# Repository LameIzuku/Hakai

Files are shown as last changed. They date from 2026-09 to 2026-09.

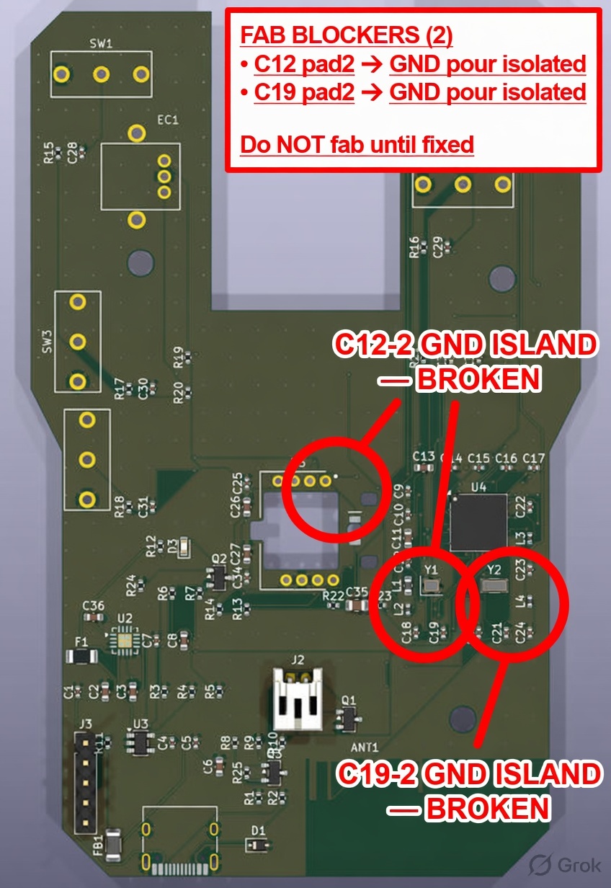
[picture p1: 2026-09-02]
hardware/v6-final-v2/FAB_BLOCKERS_GND_C12_C19_marked.jpg

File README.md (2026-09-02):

# Hakai

Hardware, firmware-adjacent tooling and web assets for the Hakai mouse.

## Repository layout

```
hardware/            KiCad projects, one folder per design revision
  rev2/                Jul 2026  - hakai_mouse_rev2
  v5/                  Jul 2026  - hakai_mouse_v5
  final/               Jul 2026  - hakai_mouse_final
  v6/                  Jul 2026  - hakai_mouse_v6
  v6-final-v2/         Aug 2026  - hakai_mouse_v6   <-- CURRENT / authoritative
site/                Product site (static HTML + assets)
docs/                Design notes and schematic write-ups
tools/               Helper scripts (Blender MCP addon, etc.)
archive/             Local-only zip snapshots (not tracked - see .gitignore)
```

Revision order is chronological by board file date. **`hardware/v6-final-v2/` is
the authoritative design**; the other folders are kept for history and should not
be fabricated from.

## Current board: `hardware/v6-final-v2`

| | |
|---|---|
| Board | 70.10 x 110.10 mm, 2 layer, 0.8 mm |
| Copper | 1 oz (35 um) both outer layers |
| Min track / clearance | 0.10 mm / 0.072 mm (QFN courtyards only; 0.20 mm elsewhere) |
| Min drill | 0.20 mm |
| Mounting holes | 3x NPTH 3.2 mm at (114,72), (155,130), (160,74) |

### Assembly note - MH3

MH3 is the NPTH 3.2 mm hole at **(155.000, 130.000)**. The ground pour is held
back 1.40 mm from the hole edge by a dedicated keepout. **Fit a nylon or other
insulating washer / standoff at MH3** - do not use a bare metal washer.

### Fabrication status: READY

The saved zone fill is current. Verified with KiCad 10.0.5:

- DRC **without** `--refill-zones` (i.e. against the *stored* fill that gerber
  export actually plots): **0 violations, 0 unconnected**
- Ground pour clearance to the MH3 hole edge: **1.3964 mm (F.Cu) / 1.3974 mm
  (B.Cu)**, measured in the exported gerber
- Mounting-hole drill: 3x NPTH 3.2 mm, MH3 at `X155.0 Y-130.0`

Ready-to-send package: **`gerbers/fab_ready/`** - 9 gerbers, merged Excellon
drill (PTH + NPTH, MixedPlating), `.gbrjob`, and `FAB_NOTES.txt`.

> **Always re-fill zones before exporting gerbers.** Gerber export plots the
> *saved* fill, not a live one. If you edit routing, run `Edit > Fill All Zones`
> (B), confirm DRC is 0/0 with "Refill all zones" *unchecked*, then save and
> re-export. An earlier revision of this board shipped a stale fill in which the
> GND pour overlapped SWDIO and VBAT_SENSE at 0.0000 mm clearance.

### Known deviation - VBAT_SENSE under the RF feed

`VBAT_SENSE` on B.Cu crosses beneath `RF_FEED` on F.Cu, with the nearest plane
cut **~1.79 mm from the antenna feed pad ANT1.1** at (138.000, 140.000).
Crossing counts are unchanged from the pre-reroute baseline (2x RF_FEED, 2x ANT,
1x RF1, all broadside through the 0.8 mm dielectric), but the baseline's closest
cut was 8.83 mm out. Accepted for prototype. If return loss disappoints, look
here before touching the match component values.

## Excluded from version control

| Excluded | Size | Why |
|---|---|---|
| `archive/*.zip` | 163 MB + 64 MB | Self-archives of this tree; the 163 MB file exceeds GitHub's 100 MB hard limit |
| `**/tools/fr/*.jar` | 58 MB each | Freerouting - download from [freerouting/freerouting](https://github.com/freerouting/freerouting/releases) |
| `.history/` | - | VS Code Local History; contains nested git repos |
| `*.kicad_prl` | - | Per-user KiCad local settings |

`.gitattributes` sets `* -text` so git never rewrites line endings. Gerber and
drill files are checksum-verified; EOL conversion would silently corrupt them.

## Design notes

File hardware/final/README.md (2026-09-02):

# HAKAI Wireless Gaming Mouse — FINAL Release Package (v5.3)

> **v5.3 — sensor/switch mechanicals brought to datasheet-exact, ADC margin doubled:**
> 1. **PAW3311 board features now EXACT per PixArt Table 9 (L0AJ-LSG1 column):** the aperture
>    cutout grows to its true size (x −7.86…+1.64 with the optical-axis notch out to −9.56,
>    y 1.38…11.23, corners R0.40 max — the v5.2 rect was undersized and the lens tower would
>    not have fit); the LED cutout is the real **R0.90 × 2.00 stadium** (was a R0.65 placeholder);
>    the **2× lens guide-post holes** (2.0 × 1.6, R0.40, x 4.58…6.58) are added — the L0AJ lens
>    self-aligns through these and can be heat-staked (PixArt assembly note 8); sensor pin holes
>    are Ø0.80 per the drawing. **D2 now uses a custom footprint** whose pads sit at the Table 9
>    "LED Soldering Pad" positions, 0.12 mm clear of the stadium (a generic 1206 would violate
>    copper-to-edge). C26/C27/R23 moved slightly to clear the new cutouts. **Verify D2's pads
>    against the final PixArt-recommended IR-LED P/N before fab.**
> 2. **Kailh boss-hole question CLOSED — no holes needed:** official Omron D2F + D2FC datasheets
>    and the Kailh GM 8.0 drawing all show a **flat switch bottom**; the "two holes" in those
>    drawings are side-face chassis-pin features 1.5 mm above the PCB. Omron's PCB pattern is
>    3× Ø1.2 terminal holes at 5.08 pitch — the footprint now matches it exactly, and its
>    silk/courtyard is fixed to the true centered 12.8 × 5.8 body (plunger marked on F.Fab).
> 3. **R25 = 47 k (was 100 k):** Q1's worst-case off-state leakage (5 µA) × 47 k = 0.24 V,
>    comfortably under Q3's 0.5 V minimum gate threshold — the paper margin that was zero at
>    100 k is now 2×. Sampling current rises to ~103 µA, still only while P0.03 is high.
> 4. **Placement + silkscreen corrections from the adversarial re-review of this revision:**
>    TP1–TP6 raised to y = 43.5 (SW2's corrected courtyard overlapped the old row and the
>    switch body would have blocked probing); SW4 moved to x = 107.2 (its true-size body
>    overhung the x = 104 board edge); R22/C35/R23 relocated to the open band below the
>    sensor (y = 115.5), fully vacating the PixArt clear zone so only U5 features + the IR
>    LED live inside the lens region; Kailh plunger marker set to x = −1.95 per the verified
>    drawings. **Silkscreen cleaned up:** custom-footprint reference designators repositioned
>    off their own pads/cutouts, the U5 body outline redrawn so it no longer crosses the
>    aperture/notch/stadium cutouts, D2 and the M3-hole refs moved to F.Fab (they sit under
>    the lens / are board-only). DRC silk warnings dropped from 38 → **4** (all harmless
>    refdes-text overlaps in the two densest corners; 0 error-severity violations besides the
>    intentional unrouted ratsnest).

> **v5.2:** C36 (10 µF) added at the BQ24074 BAT pins (Table 7-1 mandatory bypass);
> battery-sense divider re-topologized to **high-side gating** (Q3 AO3401A + R25, Q1 drives the
> gate) so AIN0 can never float above VDD and standby drain is truly zero. New nets `VBAT_SW`,
> `VBAT_SW_G`. **v5.1:** middle click = 5th Kailh GM 8.0 (SW5).

nRF52833 (integrated 2.4 GHz radio) · PixArt PAW3311DB (datasheet-verified wiring **and**
mechanicals) · 5× Kailh GM 8.0 · **split scroll wheel** (EC1 encoder + SW5 Kailh) · BQ24074
charger · **single 1.9 V system rail** · shaped mouse-plate PCB with open wheel bay.

## Contents

| File | What |
|---|---|
| `hakai_mouse_final.kicad_pro` | **Open this** in KiCad 8/9/10 |
| `hakai_mouse_final.kicad_sch` | Schematic, Rev 5.3. ERC = 0 |
| `hakai_mouse_final.kicad_pcb` | Shaped board: all footprints placed + full net assignment. **UNROUTED** |
| `hakai_mouse_final_schematic.pdf` | Plotted schematic for review |
| `board_top_render.png` | 3D top view of the board |
| `BOM_hakai_mouse_final.csv` | Grouped bill of materials (kicad-cli export) |
| `Cost_Estimate_hakai_mouse_final.csv` | Per-part cost estimates + totals (≈$18.39 parts / ≈$24.89 w/ battery) |
| `DATASHEET_hakai_mouse_final.pdf` | Product-level engineering datasheet (HAKAI M1) |
| `footprints.pretty/` + `fp-lib-table` | Custom footprints: PAW3311 iDIP-8 (full Table 9 features), IR-LED pads, Kailh GM8/D2F (verified pattern), 11 mm encoder |
| `datasheets/PAW3311DB-T2MU_v1.0.pdf` | PixArt datasheet — source of all sensor wiring + Table 9 mechanicals |
| `verification/` | ERC report, DRC report, netlist cross-check, pad-by-pad electrical audit |
| `tools/` | Python generators + checkers that build this project (run with KiCad's bundled python) |
| `build/` | Intermediate netlist (`net.net`) used by the board generator and checkers |

## v5 design highlights

- **Split scroll wheel (type B, like commercial mice):** EC1 = 11 mm rotation-only encoder on the
  **left wheel-bay wall** (D-socket accepts the wheel axle, shaft points into the bay);
  SW5 = **Kailh GM 8.0** on the **right wall** — the wheel cradle presses it for middle click,
  giving M3 the same tactility as the main buttons.
  Nets/pins: `ENC_A`→P0.08, `ENC_B`→P0.11 (nRF QDEC-compatible), `ENC_SW`→P0.12, all with 10 k pull-ups.
  Wheel/axle/cradle are shell parts, not PCB items.
- **Single 1.9 V rail** (XC6219B192MR): PAW3311 VDD abs max is 2.1 V — 3.3 V anywhere on the sensor
  is fatal; the nRF52833 runs 1.7–3.6 V so MCU + sensor share the rail, no level shifting.
  Status LED runs from VSYS via Q2 (AO3400A); SWD debug is 1.9 V logic (set probe VTref).
- **Sensor verified against the real datasheet** (v1.0, 1A009EN) — electrically *and*
  mechanically: 3-wire SDIO with the MISO-direct / MOSI-via-3.3 k bridge (R23; 1 k @ 4 MHz,
  240 Ω @ 8 MHz), VDDREG bypass-only (4.7 µF/10 V + 100 nF), MOTION push-pull, LED chain
  1V9 → 18 Ω 1% → IR LED → pin 1 (24 mA); board features exact per Table 9 (aperture + notch,
  LED stadium, guide-post holes, Ø0.80 pin holes, 0.8 mm PCB).
- **Board**: 70 × 110 mm envelope, 0.8 mm thick (sensor lens stack requires it), 2-layer.
  Open U wheel bay 24 × 38 mm between switch ears; chamfered corners; narrowed tail with
  **USB-C charge port at the tail edge**; sensor aperture/LED/guide-post cutouts inside the U5
  footprint (optical center at 135, 106); TI SWRA117D PCB antenna in a copper-free tail zone;
  3× M3 mounting holes; GND pour both layers.
- **nRF52833 support circuitry verified** against Nordic PS v1.7 + PCA10100 DK files:
  DEC3 = 100 pF (not 100 nF), DEC4+DEC6 tied (1 µF + 47 nF), DC/DC 10 µH + 15 nH,
  RF match 1.0 pF / 4.7 nH / 1.2 pF / 2.2 nH + antenna-dependent tune cap (DNP).
  BQ24074: ILIM mode 497 mA input / 445 mA charge, TS 10 k fixed, TMR/ITERM float,
  BAT bypassed by C36 10 µF at pins 2/3 (v5.2).

## Verification shipped in `verification/`

- `ERC_report.rpt` — 0 violations
- `netlist_crosscheck.txt` — 45 signal nets + 6 rails exact-match against the design intent
- `pad_audit.txt` — **every PCB pad's net compared to the schematic netlist: 0 mismatches**
  (die pad / USB shield / crystal shell / antenna stub / encoder brackets are the verified,
  whitelisted board-side extras)
- `DRC_report.rpt` — 0 error-severity violations besides the intentional unrouted ratsnest
  (KiCad rates each of the 143 missing connections as an error; the only other entries are
  4 silk-cosmetic warnings — refdes-text overlaps in the two densest corners, no electrical,
  clearance, or solder-mask impact)
- Geometric containment: every pad verified inside the shaped outline

## Before fab (the honest list)

1. **Route it** — the board is placed + netted, deliberately unrouted. RF path (nRF ANT →
   1.0 pF/4.7 nH/1.2 pF/2.2 nH → antenna): copy Nordic PCA10100 trace/ground geometry verbatim,
   50 Ω, stitch vias, then VNA-tune C24.
2. **EC1 vendor check** — pin/bracket spacing is a generic 11 mm pattern; verify against the exact
   TTC / F-switch drawing you buy.
3. **SW5 actuation** — shell cradle press travel must match the Kailh's plunger height/force
   (plunger end faces the bay); a GM 4.0 swap is drop-in if M3 ends up too easy to trigger.
4. **IR LED P/N** — D2's pads follow PixArt Table 9; confirm them against the reflow pad
   recommendation of the actual emitter you buy (PixArt names the P/N for the L0AJ-LSG1 set).
5. **Battery polarity** — JST PH has no standard; this design says pin 1 = BAT+. Verify the pigtail
   with a DMM. Use a protected cell.

*(Closed in v5.3: the old "enlarge LED cutout" item — now datasheet-exact — and the old "add
Kailh boss holes" item — investigated against official Omron/Kailh drawings; the switches have
flat bottoms and no boss holes exist to add.)*

## Firmware bring-up notes

- SPI mode 3, start ≤2 MHz (matches R23 = 3.3 k). Wake-from-shutdown needs RESET + 50 ms (tMOT-RST).
- Scroll decoding: nRF52833 **QDEC** peripheral on P0.08/P0.11; LED pin on P0.13 gates Q2 from VSYS.
- nRESET = P0.18 via UICR PSELRESET; DC/DC REG1 enabled (L fitted). Battery ADC: AIN0; drive
  P0.03 **high** to sample (Q1 pulls Q3's gate low → P-FET connects VBAT to the divider; adds
  ~103 µA through R25 + divider only while sampling). P0.03 low/high-Z = divider fully dead,
  AIN0 held at GND by R9 — true zero standby drain.

## Regenerating (reproducible build)

`tools/` contains the deterministic generators: `gen_kicad.py` (schematic), `pcb_gen.py` (board),
plus the checkers (`check_netlist.py`, `pcb_check.py`, `verify_pkg.py`, `drc_summary.py`). All
paths are **package-relative** as of v5.2 — no editing needed. Run with KiCad's bundled Python
(`C:\Program Files\KiCad\10.0\bin\python.exe`):

```
python tools/gen_kicad.py                                # rebuild schematic
kicad-cli sch export netlist --output build/net.net hakai_mouse_final.kicad_sch
python tools/pcb_gen.py                                  # rebuild board (reads build/net.net)
python tools/fill_zones.py                               # refill GND pours
python tools/check_netlist.py                            # netlist vs design intent
python tools/pcb_check.py                                # pad-by-pad PCB vs netlist audit
python tools/verify_pkg.py                               # containment/BOM/cost/inventory
```

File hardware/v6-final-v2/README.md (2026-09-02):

# HAKAI Wireless Gaming Mouse — v6.0 ROUTED Release Package

> **v6.0 = v5.3 + full routing.** The deliberately-unrouted v5.3 board is now
> **routed: all 138 signal connections placed and DRC-clean**, GND poured and
> stitched (280+ vias), with manufacturing design rules baked into the project.
> Two small GND spokes remain as documented hand-fixes (below) — everything
> else is fab-ready copper.

## ⚠️ v6.0 PIN SWAPS (firmware-relevant!)

The nRF52833's aQFN-73 west face physically cannot escape six signals on a
2-layer board (0.25 mm ball channels; vias do not fit between escape lines).
Three GPIOs moved to free balls with open escapes — **schematic + netlist +
board all updated and re-verified**; only firmware pin constants change:

| Signal | was (v5.3) | **now (v6.0)** |
|---|---|---|
| BTN_RIGHT | P0.05 (K2) | **P1.02 (W24)** |
| BTN_SIDE_BACK | P0.06 (L1) | **P1.04 (U24)** |
| VBAT_EN | P0.03 (B13) | **P1.00 (AD22)** |

(BTN_LEFT stays P0.04, BTN_SIDE_FWD stays P0.07, encoder/SPI/etc. unchanged.)

## Final verification state (all shipped in `verification/`)

- **ERC: 0 violations.** Netlist cross-check: 45 signal nets + 6 rails exact.
- **Pad audit: 306 pad↔net assignments, 0 mismatches** (post-pin-swap).
- **DRC: 0 error-severity violations.** 4 cosmetic silkscreen warnings
  (refdes overlaps, same class v5.3 documented).
- **2 unconnected items — the documented hand-fixes:** the GND pour tongues
  under **C12-2** and **C19-2** connect to their pads but not to the GND
  mainland (each pocket is sealed by routed tracks on both layers at rule
  clearance; automated repair verified-impossible without moving neighbors).
  **Fix interactively in KiCad (~5 min each):** push-and-shove the crossing
  track (STAT's B.Cu run near C12; the XL2-area diagonal near C19) a few
  tenths, then drop a GND via in the freed tongue, or drag a short GND spoke.
  Until fixed, C12 (47 nF DEC4_6 bypass) and C19 (12 pF XC2 load) are
  electrically floating — **do not fab before closing these two**.

## How it was routed (reproducible)

1. `tools/set_rules.py` — netclasses: Default 0.15/0.15 mm, power 0.30 mm,
   fine 0.10/0.075 mm (aQFN ring-2 escapes); vias 0.45/0.20; plus
   `hakai_mouse_v6.kicad_dru` courtyard relaxations.
2. **Freerouting 2.2.4** (Java 25) over a Specctra DSN export, seeded with
   deterministic ball-escape stubs: ~130 of 138 connections.
   `tools/fr_import.py` reimports the SES.
3. Local grid A* + exact-geometry checkers (`tools/routes*.py`,
   `tools/*_finish.py`) for the remaining spans, GND stitching (3.5 mm grid,
   pour-validated), the nRF EP ground tie, and pad-tongue spokes.
4. `tools/package_v6.sh` — gerbers/drill/zip/render + full verify suite.

## Fab notes

- 2 layers, **0.8 mm** (sensor lens stack requirement), gerbers in
  `GERBERS_hakai_v6_PROTO.zip` (X2, with job file).
- **Copper weight: 1 oz (35 µm) outer copper on both F.Cu and B.Cu.**
  Specify this on the fab drawing / order form (not left to fab default).
- **Advanced-prototype class**: min track 0.10 mm, min clearance 0.075 mm
  (only inside the two QFN courtyards), vias 0.45/0.20 mm, hole-to-copper
  0.20 mm. JLCPCB/PCBWay "advanced" 2-layer services cover this; confirm
  3.5 mil capability when ordering.
- RF: the antenna feed keeps the Nordic-verbatim match chain; the tail
  antenna zone is copper-free. **VNA-tune C24 (DNP) after assembly.**
- **MH3 (NPTH Ø3.2 @ 155,130) assembly: use a nylon or other insulating
  washer / standoff under the screw.** Do **not** use a bare metal washer
  that could bridge copper inside ~r=4.5 mm of the hole (SWDCLK and nearby
  copper remain in that mechanical envelope by design).
- v5.3's "before fab" list still applies: verify EC1 encoder drawing, SW5
  plunger travel, IR-LED P/N pads, and battery pigtail polarity (pin 1 = BAT+).

## Firmware bring-up deltas vs v5.3

- Buttons: right = **P1.02**, side-back = **P1.04** (active-low, 10 k pull-ups).
- Battery sampling: drive **P1.00** high (was P0.03) → Q1 → Q3 connects the
  divider; AIN0 (P0.02) unchanged.
- Everything else per v5.3 notes (SPI mode 3 ≤2 MHz start, QDEC on
  P0.08/P0.11, nRESET P0.18, DC/DC enabled).

## Contents

| File | What |
|---|---|
| `hakai_mouse_v6.kicad_pro/sch/pcb` | Rev 6.0 project — **routed** board |
| `hakai_mouse_v6_schematic.pdf` | Plotted schematic (rev 6.0, pin swaps in) |
| `board_top_render.png` | 3D render of the routed board |
| `GERBERS_hakai_v6_PROTO.zip` + `gerbers/` | Fab outputs (12 files) |
| `BOM_hakai_mouse_v6.csv`, `Cost_Estimate_hakai_mouse_v6.csv` | unchanged BOM/cost (≈$18.39/$24.89) |
| `verification/` | ERC, DRC, netlist cross-check, pad audit |
| `tools/` | generators, routers, checkers (KiCad 10 bundled python) |
| `datasheets/` | PixArt PAW3311DB, TI BQ24074, Torex XC6219 |

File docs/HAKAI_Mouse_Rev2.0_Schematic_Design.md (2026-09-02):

# HAKAI Wireless Gaming Mouse — Rev 2.0 Corrected Schematic Design

**Target spec:** Nordic nRF52833 (QIAA/aQFN73) · PixArt PAW3311DB optical sensor · 4× Kailh switches
(Left, Right, Side-Back, Side-Forward) · scroll wheel (quadrature encoder + middle click) ·
integrated 2.4 GHz radio · USB-C charging + Li-ion.

> **Note on the "2.4 GHz module":** the nRF52833 *is* the radio (BLE / Nordic ESB / Gazell). No external
> transceiver is used — the "wireless section" is the nRF internal radio + antenna matching network + PCB/chip antenna.

> **Note on the PAW3311 datasheet:** PixArt ships the PAW3311DB datasheet under NDA ("Confidential").
> Items marked **[VERIFY-DS]** below must be confirmed against the real datasheet before fab.

> **KiCad project generated from this document:** [`hakai_mouse_rev2/hakai_mouse_rev2.kicad_sch`](hakai_mouse_rev2/hakai_mouse_rev2.kicad_sch)
> (KiCad 8 format; opens in KiCad 8/9/10). Verified: parses clean, **ERC = 0 errors**, and the exported
> netlist was machine-checked pin-for-pin against §3–§8 of this document (44 signal nets exact-match, 6 rails).
>
> **REV 2.1 — sensor wiring now VERIFIED against the real PAW3311DB datasheet** (v1.0, 1A009EN — copy in
> [`hakai_mouse_rev2/datasheets/`](hakai_mouse_rev2/datasheets/PAW3311DB-T2MU_v1.0.pdf)). Consequences applied
> throughout: **the whole system runs on a single 1.9 V rail** (PAW3311 VDD abs max is 2.1 V, so 3.3 V I/O would
> destroy it; the nRF52833 runs 1.7–3.6 V so MCU + sensor share the rail with no level shifting), the SPI link is
> **3-wire SDIO** with PixArt's MISO-direct / MOSI-via-R1 bridge, and the status LED moved to VSYS behind a FET.
> Audit-table findings 6–7 are superseded by §4.

---

## 1. Audit of prototype Rev 1.1 (issues found + corrections)

| # | Ref | Issue found in prototype | Sev | Correction in Rev 2.0 |
|---|-----|---|-----|---|
| 1 | Sheet 3/6 | Encoder nets named `DEC1/DEC2/DEC_SW` collide with nRF52833 **DECx supply-decoupling** pin names → wiring/BOM confusion | High | Renamed encoder nets `ENC_A / ENC_B / ENC_SW` |
| 2 | C9,C10 on P0.00/P0.01 | 2.2 µF caps on quadrature encoder GPIO **and** P0.00/P0.01 are the dedicated **XL1/XL2 (32.768 kHz)** pins — cannot be encoder inputs | High | LFXO stays on P0.00/P0.01; encoder moved to free GPIO; caps removed from signal lines |
| 3 | D+/D- → P0.15/P0.14 | nRF52833 USB uses **dedicated D+/D- pins + VBUS + DECUSB (4.7 µF)**, not GPIO | High | USB-C made **charge-only** (recommended). Optional wired-data path documented separately |
| 4 | U1 FSUSB42A | FSUSB42 is a USB2.0 signal mux, **not** a power load switch; BQ24074 already does dynamic power-path | Med | **Deleted** |
| 5 | VDD/VDDH decoupling | Nordic requires **4.7 µF** on the shorted VDD/VDDH node (present as C16 ✓); DECx + DC/DC must match reference | Med | Kept 4.7 µF; DECx values locked to Nordic QIAA reference |
| 6 | Sensor MOTION/NCS | MOTION is **open-drain, active-low** with no pull-up; NCS floats at boot | Med | Added 10 k pull-up on MOTION and on NCS (→ VDDIO) |
| 7 | Sensor supply | Only VDDIO wired; PAW3311 may have a separate analog VDD | Med | **[VERIFY-DS]** — both-case wiring provided in §4 |
| 8 | BQ24074 | **TS** (thermal) and **ILIM** pins not handled; floating TS faults charging | High | ILIM resistor added; TS biased (or NTC); EN1/EN2/CE defined |
| 9 | OUT vs BAT | System `OUT` and cell `BAT` share the label **"BAT"** — must be separate nodes | High | Renamed **VSYS** (system) vs **VBAT** (cell) |
| 10 | Batt ADC on P0.03 | Divider node collides with encoder-switch net; 300 k divider drains ~14 µA always | Med | Dedicated **AIN0 (P0.02)**; divider gated by a FET on P0.03 |
| 11 | RF match (2.7nH/3.3nH/1.2pF/1.0pF) | Values differ from Nordic reference; RF is layout-dependent | High | **Copy Nordic nRF52833 QIAA RF network verbatim** + tune antenna with VNA (§8) |
| 12 | U7 74LVC1G14 on DPI | Schmitt buffer unnecessary (firmware debounce); DPI button not in new spec | Low | **Removed** |
| 13 | XC6219 3.3 V LDO | Drops out below ~3.5 V cell → 3V3 sags with battery | Info | Acceptable (caps sensor ≤3.3 V, protects 3.6 V max). Buck-boost optional for full runtime |

---

## 2. Power tree

```
USB-C VBUS(5V) ──► BQ24074 ─┬─ BAT ◄──► Li-ion cell (J_BAT)   [charge]
   (charge-only)            └─ OUT = VSYS ──► F1(PTC) ──► XC6219B192MR 1.9V LDO ──► 1V9
                                                                                    │
                                             FB1 (ferrite 600Ω@100MHz) ──► 1V9_A (clean rail)
   1V9_A powers: nRF52833 (VDD/VDDH), PAW3311 VDD + VLED, all pull-ups
   VSYS powers:  status LED (via Q2 AO3400A low-side switch — 1.9V can't light a blue LED)
   VBAT ──► [FET-gated 200k/100k divider] ──► nRF AIN0 (fuel gauge; 4.2V/3 = 1.4V < 1.9V ✓)
```
Rail summary: **VBUS** 5 V (USB) · **VBAT** 3.0–4.2 V (cell) · **VSYS** ≈ VBAT/5 V (power-path) ·
**1V9** system logic · **1V9_A** clean analog/RF (ferrite-isolated).

> **Why 1.9 V:** PAW3311 VDD = 1.8–2.1 V with **abs max 2.1 V on VDD and every I/O pin** — 3.3 V anywhere on it
> is fatal. Running the nRF52833 at the same 1.9 V eliminates all level shifting. Debug note: set your SWD
> probe's VTref for 1.9 V logic. FETs on this board must be low-Vth (AO3400A, not 2N7002).

---

## 3. nRF52833 (U4, QIAA/aQFN73) — pin map & supply

**Supply / DC-DC — copy Nordic QIAA reference circuit component-for-component:**

**VERIFIED against Nordic PS v1.7 §7.3 + PCA10100 DK 2.0.0 design files:**

| Pin (ball) | Connection | Value |
|---|---|---|
| VDD (A22, B1, W1, AD14, AD23) + VDDH (Y2) shorted | 3V3_A | bulk **4.7 µF** (W1) + 1 µF (B1) + 100 nF × 3 (A22/AD14/AD23) |
| DEC1 (C1) | GND | 100 nF X7R |
| DEC3 (D23) | GND | **100 pF NP0** ⚠️ (common error is fitting 100 nF here — Nordic specifies 100 pF) |
| DEC4 (B5) + DEC6 (E24) | tied together = net `DEC4_6` | **1.0 µF** + **47 nF** (47 nF fitted in DC/DC configs) |
| DEC5 (N24) | — | N.C. on build codes **Bxx and later** (820 pF only for Axx silicon — spec QIAAB0+) |
| DCC (B3) | → `DEC4_6` via inductors | **10 µH (0603) + 15 nH (0402) in series** (REG1 DC/DC mode) |
| DECUSB (AC5), VBUS (AD2), D+ (AD6), D− (AD4) | **leave floating** | Nordic no-USB reference config 6 (charge-only design) |

> There is **no DEC2** and **no DCCH** on the nRF52833 (REG0 is LDO-only, unlike nRF52840).
> DC-DC (REG1) roughly halves active radio current — implemented in this design.
> nRESET is **P0.18 (AC13)** mapped via UICR `PSELRESET[0/1]` — there is no dedicated reset ball.

**GPIO assignment (clean, conflict-free):**

| Function | nRF signal | Net |
|---|---|-----|
| HFXO 32 MHz | XC1 / XC2 (dedicated) | Y1 + 2×12 pF |
| LFXO 32.768 kHz | P0.00 / P0.01 (XL1/XL2, dedicated) | Y2 + 2× caps to match crystal CL |
| Sensor SPI clock | P0.20 | `SPI_SCK` |
| Sensor SPI MOSI | P0.22 | `SPI_MOSI` → **R1 3.3 k** → `SENS_SDIO` (3-wire bridge) |
| Sensor SPI MISO | P0.24 | `SENS_SDIO` (**direct** on the SDIO pin) |
| Sensor chip-select | P0.17 | `SENS_NCS` (10 k PU) |
| Sensor motion IRQ | P0.19 | `SENS_MOTION` (push-pull active-low; PU optional) |
| Left click | P0.04 | `BTN_LEFT` |
| Right click | P0.05 | `BTN_RIGHT` |
| Side back | P0.06 | `BTN_SIDE_BACK` |
| Side forward | P0.07 | `BTN_SIDE_FWD` |
| Encoder A | P0.08 | `ENC_A` |
| Encoder B | P0.11 | `ENC_B` |
| Middle click (wheel push) | P0.12 | `ENC_SW` |
| Status LED | P0.13 | `LED_STAT` |
| Battery ADC | P0.02 (AIN0) | `VBAT_SENSE` |
| ADC divider enable | P0.03 | `VBAT_EN` |
| Charge status /CHG | P0.14 | `STAT` (optional) |
| Power good /PG | P0.15 | `PGOOD` (optional) |
| SWDIO / SWDCLK | dedicated | debug header J3 |
| Reset | P0.18 | `nRESET` (10 k PU) |

> **Do not use P0.09 / P0.10** as ordinary GPIO unless you reconfigure them from NFC in UICR
> (`CONFIG_NFCT_PINS_AS_GPIOS`). They are left unused here.

---

## 4. PAW3311 optical sensor (U5) — SPI + power

> **VERIFIED — PixArt datasheet v1.0 (1A009EN, 15 Nov 2022), Table 1 + Figure 6.** 8-pin staggered DIP.
> Key electricals: **VDD 1.8–2.1 V (abs max 2.1 V — all I/O abs max = VDD)** · 3-wire SPI, fSCLK ≤ 8 MHz ·
> run 2.3 mA (LPGM, incl. LED) · power-down 3 µA · up to 12,000 cpi, 300 ips, 35 g · Ta 0–40 °C ·
> VDD rise time 0.15–20 ms · transient supply up to 70 mA during ramp.

| Pin | Function (verified) | Net | Wiring (per Figure 6) |
|----|---|-----|----|
| 1 | LED — illumination control | `SENS_LED` | chain: 1V9_A(VLED, 33 µF bulk) → **R_LED 18 Ω 1%** → IR LED → pin 1 (24 mA internally controlled) |
| 2 | VDDREG — internal LDO out | `VDDREG` | **bypass only: 4.7 µF/10 V + 100 nF to GND.** Never connects to the MCU |
| 3 | VDD | 1V9_A | 10 µF + 100 nF at the pin |
| 4 | SCLK | `SPI_SCK` | nRF P0.20 |
| 5 | MOTION — active-low, push-pull | `SENS_MOTION` | nRF P0.19 (pull-up optional/DNP) |
| 6 | GND | GND | plane |
| 7 | SDIO — bidirectional data | `SENS_SDIO` | **nRF MISO (P0.24) direct** + **nRF MOSI (P0.22) via R1** — PixArt's 3-wire↔4-wire bridge |
| 8 | NCS — active low | `SENS_NCS` | nRF P0.17 + 10 k PU → 1V9_A |

**R1 (SDIO series, 1%):** 3.3 k @ 2 MHz · 1.0 k @ 4 MHz · 240 Ω @ 8 MHz. Load cap limit 20 pF on SDIO/MOTION.
Timing: tSRAD 2 µs, tSWW/tSWR 5 µs, NCS→SCLK 120 ns, wake-from-shutdown needs RESET + 50 ms motion delay.

**Optics:** LM31-LNG / LM33-LSG / L0AL-LSG1 (5 mm IR emitter) or L0AJ-LSG1 (SMT IR, 1206). Lens-to-surface
**Z = 2.20–2.60 mm**. Wave-solder with a flux-protection fixture; keep Kapton apertures on until final assembly
(datasheet §4.2). Local copy: [`datasheets/PAW3311DB-T2MU_v1.0.pdf`](hakai_mouse_rev2/datasheets/PAW3311DB-T2MU_v1.0.pdf).

---

## 5. Switches, encoder, LED

**4× Kailh switches — active-low, one 10 k pull-up each to 3V3_A, 100 nF across each for RC debounce (optional; firmware debounce also used):**

| Switch | Net | nRF |
|---|-----|-----|
| SW1 Left (main) | `BTN_LEFT` | P0.04 |
| SW2 Right (main) | `BTN_RIGHT` | P0.05 |
| SW3 Side Back | `BTN_SIDE_BACK` | P0.06 |
| SW4 Side Forward | `BTN_SIDE_FWD` | P0.07 |

Each: `switch` between GPIO and GND; `10 k` from GPIO to 3V3_A. (nRF internal pull-ups can replace external — but external is more robust.)

**Scroll wheel — mechanical quadrature encoder E1 with integrated push switch:**

| Encoder pin | Net | nRF |
|---|-----|-----|
| A | `ENC_A` | P0.08 (10 k PU + 0.01 µF to GND) |
| B | `ENC_B` | P0.11 (10 k PU + 0.01 µF to GND) |
| Common (C) | GND | — |
| SW (push = middle click) | `ENC_SW` | P0.12 (10 k PU) |

> Small RC (10 k / 10 nF) on A/B tames mechanical contact bounce; keep caps ≤10 nF so edges stay crisp.

**Status LED (D3):** VSYS → 1 k → LED → **Q2 (AO3400A)** → GND; gate = nRF P0.13 + 100 k pulldown.
(Moved off the logic rail: 1.9 V cannot forward-bias a blue LED, and direct GPIO sinking from VSYS
would leak with a 1.9 V-high pin.) Optional.

---

## 6. Charging & power (BQ24074, U2)

| BQ24074 pin | Connection | Notes |
|---|---|---|
| IN | VBUS (USB-C) | 1 µF + 10 µF input |
| OUT | **VSYS** | 10 µF; feeds F1→LDO. **Separate from BAT** |
| BAT | **VBAT** (cell + J_BAT) | 10 µF; single Li-ion |
| ISET | R to GND | ICHG = 890/R_ISET. R=2.0 k → **445 mA** |
| ILIM | R to GND | I_IN_LIM = 1600/R_ILIM. R=3.24 k → **~494 mA** (USB500) |
| /CE | GND (or MCU) | low = charge enabled |
| EN1, EN2 | set per truth table | choose USB100 / USB500 / ILIM mode |
| TS | NTC to VBAT pack **or** 10 k/10 k divider to keep in-window | **must not float** |
| /CHG, /PG | STAT (P0.14), PGOOD (P0.15) | open-drain, add 100 k PU (optional) |
| PAD/VSS | GND | thermal pad |

**LDO (XC6219B332MR, U3):** VSYS → F1 (PTC 1 A) → LDO IN; OUT = 3V3; 1 µF in + 10 µF out; CE tied to enable.
**Rail split:** 3V3 → FB1 (600 Ω @100 MHz ferrite) → **3V3_A** with 100 nF + 10 µF (clean rail for nRF + sensor + RF).

**Protection:** use a protected Li-ion cell, or add a DW01A + dual-MOSFET (e.g. 8205A) pack-protection front-end on VBAT.

**Fuel gauge:** VBAT → 200 k (R15) → node → 100 k (R16) → drain of small NFET → GND; node → nRF AIN0 (P0.02);
FET gate = `VBAT_EN` (P0.03). Divider only conducts during a reading → zero standby drain.

---

## 7. Clocks

| Osc | Xtal | Load caps | Notes |
|-----|---|---|---|
| HFXO (mandatory for radio) | Y1 32 MHz, CL 8 pF, ESR/load per Nordic list | 2× 12 pF (C_HF) | Must be on Nordic's approved crystal list; short traces |
| LFXO (recommended, low-power) | Y2 32.768 kHz | 2× caps sized to crystal CL: C ≈ 2·(CL − Cstray). For CL 9 pF → ~12 pF | Enables accurate BLE timing / low sleep current |

---

## 8. 2.4 GHz radio section (RF)

- The nRF52833 single-ended `ANT` output drives an **impedance-matching network** into a **PCB or chip antenna**.
- **Verified reference values** (identical in PS v1.7 reference configs and the PCA10100 DK):
  `ANT (H23) → shunt 1.0 pF NP0 → series 4.7 nH (LQG15HS) → shunt 1.2 pF NP0 → series 2.2 nH (LQG15HS) → 50 Ω feed`,
  plus one **antenna-dependent shunt tune cap** at the antenna feed (Nordic BOM: "Ctune — antenna dependent"; DNP until VNA-tuned).
- **Copy the RF trace/ground geometry from the reference layout too** — the match is meaningless without the exact
  stack-up and antenna. (The prototype's 2.7 nH/3.3 nH/1.2 pF/1.0 pF were not the reference values.)
- Keep the RF path 50 Ω, ground the shunt cap nearest the radio to the VSS pin closest to ANT, and keep a
  copper keep-out under the antenna.
- After building: **tune with a VNA** to the antenna's real feed impedance, then verify with a spectrum analyzer
  for FCC/CE harmonics before production.

---

## 9. Debug / test

- **J3 SWD header:** 3V3, SWDIO, SWDCLK, nRESET, GND.
- **Test points:** VBUS, VBAT, VSYS, 3V3, 3V3_A, SPI_SCK/MOSI/MISO, SENS_NCS, SENS_MOTION.

---

## 10. Bill of Materials (key parts)

| Ref | Part | Value/MPN | Notes |
|-----|---|---|---|
| U4 | Nordic nRF52833 | nRF52833-QIAA | MCU + 2.4 GHz radio |
| U5 | PixArt PAW3311DB | PAW3311DB-T2MU | optical sensor (NDA datasheet) |
| U2 | TI charger | BQ24074 | Li-ion + power path |
| U3 | Torex LDO | **XC6219B192MR** | **1.9 V** / 240 mA (system rail) |
| Q1, Q2 | N-MOSFET | AO3400A (SOT-23) | low-Vth — 2N7002 is marginal with a 1.9 V gate |
| R_LED | Resistor | 18 Ω 1% | IR LED chain (24 mA) |
| R1(SDIO) | Resistor | 3.3 k 1% | MOSI→SDIO bridge (2 MHz; 1 k @ 4 MHz, 240 Ω @ 8 MHz) |
| C(VDDREG) | Caps | 4.7 µF/10 V + 100 nF | sensor pin 2 bypass |
| C(VLED) | Cap | 33 µF | LED-chain bulk |
| Y1 | Crystal | 32 MHz (Nordic-approved) | HFXO |
| Y2 | Crystal | 32.768 kHz | LFXO |
| L_RF | RF match | **per Nordic QIAA ref** | do not substitute |
| L_DCDC | Inductor | 10 µH | if DC-DC enabled |
| FB1 | Ferrite | 600 Ω @100 MHz, 1206 | 3V3→3V3_A |
| F1 | PTC fuse | 1 A hold | VSYS |
| SW1–4 | Kailh switch | Kailh mechanical ×4 | L/R/back/fwd |
| E1 | Encoder | quadrature + push | scroll wheel |
| C(VDD) | Cap | 4.7 µF + 100 nF | VDD/VDDH node |
| C(DEC) | Caps | 100 nF ×DECx, 1 µF DEC4 | per Nordic ref |
| C(sens VDD) | Caps | 10 µF + 100 nF (at pin 3) | sensor supply |
| R(PU) | Resistor | 10 k ×(buttons, NCS, MOTION, enc) | pull-ups |
| R_ISET | Resistor | 2.0 k | 445 mA charge |
| R_ILIM | Resistor | 3.24 k | ~500 mA input limit |
| R15/R16 | Resistor | 200 k / 100 k | battery divider |
| J1 | USB-C | Type-C recept | charge |
| J_BAT | JST | 2-pin | Li-ion cell |

---

## 11. Pre-fab verification checklist

- [x] ~~[VERIFY-DS]~~ **RESOLVED (datasheet v1.0):** single VDD 1.8–2.1 V (abs max 2.1 V) → system rail = 1.9 V;
      3-wire SDIO + R1 bridge; VDDREG bypass-only; MOTION push-pull; LED chain 18 Ω @ 24 mA.
- [x] ~~[VERIFY-DS]~~ **RESOLVED:** lens LM31-LNG/LM33-LSG/L0AL-LSG1 (5 mm) or L0AJ-LSG1 (SMT); Z = 2.20–2.60 mm.
- [ ] nRF52833 supply/DEC/DC-DC caps + RF network **matched to Nordic QIAA reference** and layout copied.
- [ ] HFXO crystal is on Nordic's approved list.
- [ ] BQ24074 TS pin biased (not floating); ILIM/ISET/EN1/EN2/CE set for your cell + USB current.
- [ ] VSYS and VBAT are separate nets; power-path verified.
- [ ] P0.00/P0.01 reserved for LFXO; P0.09/P0.10 unused (NFC) unless reconfigured.
- [ ] RF tuned with VNA; emissions checked before production.
```

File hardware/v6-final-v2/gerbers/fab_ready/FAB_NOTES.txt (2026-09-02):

hakai_mouse_v6 - PROTOTYPE FABRICATION NOTES
=============================================
Generated 2026-09-02 from hakai_mouse_v6.kicad_pcb (zones refilled).
KiCad 10.0.5. Units: mm. Gerber X2, 4.6 absolute. Drill: Excellon, absolute, metric.

BOARD
  Size            : 70.10 x 110.10 mm
  Layers          : 2 (F.Cu / B.Cu)
  Board thickness : 0.8 mm
  Min track width : 0.10 mm
  Min clearance   : 0.072 mm (confined to U2/U4 QFN courtyards; 0.20 mm elsewhere)
  Min drill       : 0.20 mm
  Surface finish  : fab standard (ENIG preferred for the aQFN-73)

*** COPPER WEIGHT: 1 oz (35 um) on BOTH outer layers. ***

FILE LIST
  hakai_mouse_v6-F_Cu.gtl          Copper, top
  hakai_mouse_v6-B_Cu.gbl          Copper, bottom
  hakai_mouse_v6-F_Mask.gts        Solder mask, top
  hakai_mouse_v6-B_Mask.gbs        Solder mask, bottom
  hakai_mouse_v6-F_Paste.gtp       Paste, top
  hakai_mouse_v6-B_Paste.gbp       Paste, bottom
  hakai_mouse_v6-F_Silkscreen.gto  Legend, top
  hakai_mouse_v6-B_Silkscreen.gbo  Legend, bottom (intentionally EMPTY - no bottom-side parts)
  hakai_mouse_v6-Edge_Cuts.gm1     Board profile
  hakai_mouse_v6.drl               Drill, PTH + NPTH merged (MixedPlating)
  hakai_mouse_v6-job.gbrjob        Gerber job file

DRILL
  Single merged Excellon file, plated and non-plated in one file (MixedPlating header).
  NPTH tools: T10 = 0.65 mm, T11 = 3.20 mm.
  T11 (3.20 mm NPTH) mounting holes at: (114.0, 72.0), (155.0, 130.0), (160.0, 74.0).

ASSEMBLY NOTE - MH3
  MH3 is the NPTH 3.2 mm hole at (155.000, 130.000).
  Ground pour is held back 1.40 mm from this hole edge by design.
  *** Use a NYLON or other INSULATING washer / standoff under the screw at MH3. ***
  Do NOT fit a bare metal washer here.

DRC
  0 violations, 0 unconnected, checked against the as-shipped (stored) zone fill.

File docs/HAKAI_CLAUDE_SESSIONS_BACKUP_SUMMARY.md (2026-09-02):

# HAKAI / Claude Sessions — Full Backup Summary

**Created:** 2026-08-08  
**Source folder:** `C:\Users\kavya\Documents\hakai\claud`  
**Also present:** `C:\Users\kavya\Documents\hakai\claud-20260808T140241Z-1-001.zip` (zip archive of this tree)

> **Important note on “sessions”**  
> This folder is a **project artifact dump** from Claude-assisted work (KiCad packages, docs, web, Blender MCP), **not** Claude Code transcript logs.  
> - Local Claude config here: `.claude/settings.local.json`, `.claude/launch.json` only.  
> - No `~/.claude/projects` session transcripts were found on this machine.  
> Content below is reconstructed from READMEs, design docs, verification reports, BOM/cost CSVs, and package structure.

---

## 1. Project in one line

**HAKAI (aka HAKAI M1 / “HAKAI WRATH”)** — wireless gaming mouse PCB + product packaging:

| Item | Spec |
|---|---|
| MCU + radio | Nordic **nRF52833-QIAA** (aQFN73), integrated 2.4 GHz |
| Sensor | PixArt **PAW3311DB-T2MU** (12k CPI class), L0AJ lens stack |
| Switches | **5× Kailh GM 8.0** (L/R/side×2/middle) |
| Scroll | Split wheel: **EC1** 11 mm encoder + **SW5** Kailh middle-click |
| Power | USB-C charge-only → **BQ24074** → **XC6219 1.9 V** system rail + Li-ion |
| Board | 2-layer, **0.8 mm**, ~70×110 mm mouse-plate, PCB IFA antenna |
| Cost (est.) | ~**$18.39** parts / ~**$24.89** with battery |

---

## 2. What was previously done (task log by era)

### A. Rev 1.1 → Rev 2.0/2.1 — Schematic audit & redesign
**Artifact:** `HAKAI_Mouse_Rev2.0_Schematic_Design.md`, `hakai_mouse_rev2/`

| Done | Detail |
|---|---|
| Prototype audit | 13 issues logged from Rev 1.1 (encoder/DEC name collision, XL1/XL2 misuse, USB-on-GPIO mistake, FSUSB42 deleted, BQ24074 TS/ILIM, VSYS vs VBAT naming, RF match wrong, etc.) |
| Power tree redesign | Single **1.9 V** rail (PAW3311 abs max 2.1 V); VSYS / VBAT / 1V9 / 1V9_A split |
| nRF52833 pin map | Conflict-free GPIO; Nordic DEC/DC-DC/RF copied from PS + PCA10100 |
| PAW3311 verified | Real datasheet v1.0: 3-wire SDIO + R1 bridge, VDDREG bypass-only, LED chain 18 Ω |
| KiCad schematic gen | ERC = 0; netlist machine-checked vs design doc |
| Custom footprints | PAW3311 iDIP-8, Kailh GM8/D2F, 11 mm encoder |
| BOM + cost estimate | Generated for rev2 package |

### B. Rev 4.x–5.0 — Shaped PCB placement (still unrouted)
**Artifact:** evolution inside `hakai_mouse_rev2/` README narrative

| Done | Detail |
|---|---|
| Schematic layout cleanup (v3) | Cleaner sheet organization |
| Mouse-plate outline (v4.1) | U wheel bay 24×38 mm, chamfered corners, narrowed tail, USB-C at tail |
| Sensor cutouts | Aperture + LED cutouts per PixArt Table 9 |
| Mounting | 3× M3 holes; antenna copper-free tail zone |
| Pad electrical audit | 0 pad↔net mismatches vs schematic |
| Split scroll (Rev 5.0) | EC1 left bay wall + SW5 tact right bay wall (type B commercial style) |

### C. v5.1 — Switch unification
**Artifact:** `hakai_mouse_v5/`

| Done | Detail |
|---|---|
| SW5 → Kailh GM 8.0 | Middle click same part as main buttons (BOM SW1–SW5 qty 5) |
| Full package | Sch/PCB unrouted, BOM, cost (~$17.72 / $24.22), verification suite |
| Generators | `tools/gen_kicad.py`, `pcb_gen.py`, netlist/pad checkers |

### D. v5.2–5.3 — “FINAL” mechanical + electrical hardening
**Artifact:** `final/` (`hakai_mouse_final.*`)

| Done | Detail |
|---|---|
| v5.2 high-side battery sense | Q3 AO3401A + R25; nets `VBAT_SW` / `VBAT_SW_G`; C36 10 µF on BQ BAT |
| v5.3 sensor mechanicals | Datasheet-exact aperture/notch, LED stadium R0.90×2.00, 2× guide-post holes, Ø0.80 pins |
| Custom IR-LED footprint | Pads at Table 9 positions (not generic 1206) |
| Kailh footprint corrected | Flat bottom; Omron D2F pattern; **no boss holes** (investigated & closed) |
| R25 = 47 k | Doubled ADC off-state margin vs Q3 Vgs(th) |
| Placement/silk cleanup | TP row, SW4 edge, sensor clear zone, silk warnings 38 → 4 |
| Product datasheet PDF | `DATASHEET_hakai_mouse_final.pdf` |
| Cost | ~$18.39 parts / $24.89 w/ battery |
| State | **Placed + netted, deliberately unrouted** (143 ratsnest “errors” intentional) |

### E. v6.0 — Full routing + fab package
**Artifacts:** `v6/`, `final v2 (v6)/` (release-oriented twin; second also has `USAGE_MANUAL.md` + multi-angle renders)

| Done | Detail |
|---|---|
| Full routing | **138** signal connections; Freerouting 2.2.4 + custom A*/finish scripts |
| Design rules | Netclasses + `hakai_mouse_v6.kicad_dru`; fine 0.10/0.075 mm in QFN |
| GND | Pour both layers, **280+** stitch vias, EP ground tie |
| Pin swaps (fab necessity) | BTN_RIGHT P0.05→**P1.02**; BTN_SIDE_BACK P0.06→**P1.04**; VBAT_EN P0.03→**P1.00** |
| Gerbers | `GERBERS_hakai_v6_PROTO.zip` + drill + job file |
| Verification | ERC 0; pad audit 306/0 mismatches; DRC 0 error-severity except **2 documented GND tongue hand-fixes** (C12-2, C19-2) |
| Usage manual | Bring-up, assembly order, pin map, hand-fix procedure, RF tune notes |
| Repro tools | Large `tools/` set: route/finish/zone/package scripts + freerouting jar |

### F. Marketing site + 3D assets
**Artifact:** `site/`

| Done | Detail |
|---|---|
| Landing page | `index.html` — brand **HAKAI WRATH** |
| Buy page | `buy.html` |
| 3D preview | `preview.html` + `assets/hakai.obj` + PBR maps (diffuse, normal, roughness, metalness) |
| Product photos | front/back/left/top/etc. PNGs |
| Local server | `server.ps1` |
| v2 site | `site/v2/` (index + buy) |

### G. Blender MCP tooling
**Artifact:** `blender_mcp_addon.py` (~118 KB)

| Done | Detail |
|---|---|
| Blender ↔ Claude MCP | Addon to connect Blender to Claude via MCP (BlenderMCP / Siddharth Ahuja lineage) |
| Purpose in this project | Likely shell/3D model iteration for the mouse (pairs with `site/assets`) |

### H. Claude project permissions (meta)
**Artifact:** `.claude/settings.local.json`

Allowed: WebSearch; fetch Nordic docs / GitHub; `artifact-design` skill.

---

## 3. Topics summarized separately

### Topic 1 — Electrical architecture
- **Why 1.9 V:** PAW3311 VDD/I/O abs max **2.1 V**; nRF runs 1.7–3.6 V → shared rail, no level shifters.  
- **Charger:** BQ24074 power-path; USB-C is **charge-only** (not full USB data on nRF USB pins).  
- **Rails:** VBUS 5 V → VSYS (OUT) / VBAT (cell) → PTC → 1.9 V LDO → ferrite → clean 1V9_A for MCU/sensor/RF.  
- **LED:** Blue status LED from **VSYS** via low-side AO3400A (1.9 V cannot light blue LED).  
- **Battery ADC:** High-side gated divider; sample only when VBAT_EN high (~103 µA); zero standby when off.  
- **Charge setpoints:** ~445 mA charge / ~497 mA input limit (ISET/ILIM resistors).

### Topic 2 — Sensor (PAW3311) & optics
- 8-pin staggered DIP, **3-wire SPI** (MISO direct, MOSI via R23 3.3 k @ ≤2 MHz start).  
- VDDREG pin: **bypass only** (never to MCU).  
- LED chain: 1V9 → 18 Ω → IR LED → pin 1 (internal 24 mA control).  
- PCB thickness **0.8 mm** for lens Z = 2.20–2.60 mm.  
- v5.3+ board features match PixArt Table 9 (L0AJ-LSG1): aperture, stadium LED cutout, guide posts.

### Topic 3 — MCU, RF, clocks
- HFXO 32 MHz + LFXO 32.768 kHz on dedicated pins.  
- DEC3 = **100 pF** (not 100 nF); DEC4+DEC6 tied; DC/DC 10 µH + 15 nH.  
- RF match Nordic-verbatim: 1.0 pF / 4.7 nH / 1.2 pF / 2.2 nH + C24 DNP tune.  
- Antenna: TI SWRA117D PCB IFA, copper-free tail; **VNA-tune after assemble**.

### Topic 4 — Mechanics / UI switches
- 5× Kailh GM 8.0; split scroll (encoder + separate middle Kailh).  
- Open U wheel bay; shell owns wheel/axle/cradle.  
- Encoder footprint generic 11 mm — **must match purchased vendor drawing**.  
- Kailh “boss holes” myth closed: flat bottom, no PCB boss holes.

### Topic 5 — PCB layout & manufacturing
- Evolved unrouted placement packages → fully routed v6.  
- 2-layer advanced prototype: 0.10 mm track / 0.075 mm clearance (QFN only).  
- aQFN-73 west-face escape forced **3 pin swaps** (firmware must match v6).  
- **Blocking fab issue:** 2 GND pour tongues (C12, C19) still need interactive hand-fix → then re-export gerbers.  
- Silk: 4 cosmetic warnings remaining.

### Topic 6 — Tooling / automation
- Deterministic Python generators for schematic + PCB (KiCad 10 bundled Python).  
- Checkers: netlist intent, pad audit, DRC summary, package verify.  
- Routing pipeline: Specctra DSN → Freerouting → SES import → hand finish scripts.  
- `package_v6.sh` regenerates gerbers/renders/reports.

### Topic 7 — Product / web / brand
- Branding **HAKAI WRATH** (“Break everything between you and the shot”).  
- Static marketing site + 3D OBJ preview assets.  
- Engineering datasheet PDFs in final/v6 packages.

### Topic 8 — What’s NOT done (open work)
1. **Close C12-2 / C19-2 GND hand-fixes** in KiCad; re-run DRC → unconnected = 0.  
2. Re-export `GERBERS_hakai_v6_PROTO.zip` after hand-fixes.  
3. Vendor-verify EC1 encoder + IR LED exact P/N pads + battery pigtail polarity.  
4. **Firmware** (nRF52) — pin map documented; no firmware tree in this folder.  
5. Shell/mechanical CAD beyond web 3D assets; assembly of first proto.  
6. VNA antenna tune (C24); regulatory/emissions later.  
7. Claude **chat transcripts** not archived here — only work products.

---

## 4. Version lineage (which folder to open)

| Folder | Role | Board state | Prefer for… |
|---|---|---|---|
| `hakai_mouse_rev2/` | Early Rev 2–5.0 path | Unrouted | History / early netlist |
| `hakai_mouse_v5/` | v5.1 package | Unrouted | Mid history |
| `final/` | **v5.3 FINAL** placed package | Unrouted, mech-correct | Pre-route reference |
| `v6/` | **v6.0 routed** + routing archaeology | Routed + build intermediates | Deep routing debug |
| `final v2 (v6)/` | **v6.0 release-style** (+ USAGE_MANUAL, multi-renders) | Routed | **Best “ship” package to open** |
| `site/` | Marketing / 3D web | N/A | Landing page |
| `HAKAI_Mouse_Rev2.0_Schematic_Design.md` | Master electrical design prose | N/A | Why decisions exist |
| `blender_mcp_addon.py` | Blender MCP addon | N/A | 3D workflow |

**Recommended “current truth” for hardware:**  
`final v2 (v6)/` (or `v6/` if you need the full routing script history).

---

## 5. Firmware pin map (v6.0 — use this, not v5.3)

| Function | Pin | Notes |
|---|-----|---|
| BTN_LEFT | P0.04 | active-low |
| **BTN_RIGHT** | **P1.02** | swapped from P0.05 |
| **BTN_SIDE_BACK** | **P1.04** | swapped from P0.06 |
| BTN_SIDE_FWD | P0.07 | |
| ENC_A / ENC_B | P0.08 / P0.11 | QDEC |
| ENC_SW | P0.12 | SW5 |
| SPI SCK / MOSI / MISO | P0.20 / P0.22 / P0.24 | mode 3, ≤2 MHz start |
| SENS_NCS / MOTION | P0.17 / P0.19 | |
| LED_STAT | P0.13 | gates Q2 from VSYS |
| STAT / PGOOD | P0.14 / P0.15 | charger |
| **VBAT_EN** | **P1.00** | swapped from P0.03; drive HIGH to sample |
| VBAT_SENSE | P0.02 (AIN0) | |
| nRESET | P0.18 | UICR PSELRESET |
| SWD | J3 | **VTref = 1.9 V** |

---

## 6. Key file index (quick restore map)

```
claud/
├── HAKAI_CLAUDE_SESSIONS_BACKUP_SUMMARY.md   ← this file
├── HAKAI_Mouse_Rev2.0_Schematic_Design.md    ← electrical design bible
├── blender_mcp_addon.py
├── .claude/                                  ← permissions only (no transcripts)
├── hakai_mouse_rev2/                         ← early KiCad
├── hakai_mouse_v5/                           ← v5.1
├── final/                                    ← v5.3 unrouted “FINAL”
├── v6/                                       ← routed + tools + DSN/SES history
├── final v2 (v6)/                            ← best release package + USAGE_MANUAL
│   ├── hakai_mouse_v6.kicad_pro/sch/pcb
│   ├── GERBERS_hakai_v6_PROTO.zip
│   ├── BOM_ / Cost_Estimate_ / DATASHEET_
│   ├── USAGE_MANUAL.md
│   ├── verification/
│   └── tools/
└── site/                                     ← HAKAI WRATH web + 3D assets
```

---

## 7. Safest next actions (if continuing the project)

1. Open `final v2 (v6)/hakai_mouse_v6.kicad_pcb` in KiCad 8/9/10.  
2. Apply the two GND hand-fixes (USAGE_MANUAL §6); refill zones; DRC → 0 unconnected.  
3. Re-run `tools/package_v6.sh` (or KiCad plot) for fresh gerbers.  
4. Order **2-layer 0.8 mm advanced** PCB + top stencil; source BOM.  
5. Start nRF firmware using **v6 pin map**.  
6. Optional: drop final prototype project files here or beside this folder for a delta review against v6.

---

## 8. Uncertainty / caveats

- Summaries are from **artifacts**, not live chat logs — conversational intent (why certain experiments) may be incomplete.  
- `final/` vs `final v2 (v6)/` vs `v6/` may differ slightly in tooling noise; release docs agree on electrical intent of v6.  
- Dates on files (e.g. design md ~2026-07-04, DRC report 2026-07-12) mark the hardware sprint; this backup was written 2026-08-08.  
- Do not fab v6 gerbers until C12/C19 GND tongues are fixed and gerbers re-exported.

---

*End of backup summary.*

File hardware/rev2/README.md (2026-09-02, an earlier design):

# HAKAI Wireless Gaming Mouse — Rev 5.0 KiCad Project

> **Rev 5.0 — split scroll wheel (type B, like commercial mice):** the integrated
> push-encoder is replaced by **EC1** (11 mm rotation-only encoder, LEFT bay wall,
> D-socket takes the wheel axle) + **SW5** (6×6 tact, RIGHT bay wall — the cradle
> arm presses it for middle click). Same nets, same MCU pins (`ENC_A` P0.08,
> `ENC_B` P0.11, `ENC_SW` P0.12). Wheel/axle/cradle are shell parts.
> Verify EC1's pin/bracket spacing against the chosen vendor drawing before fab.

> **Rev 4.1** = Rev 2.1 electrical design (netlist unchanged since datasheet verification) +
> schematic layout cleanup (v3) + shaped mouse-plate PCB (v4.1, modeled on a commercial DIY mouse board):
> - **U-shaped wheel bay** (24×38 mm, open at the front edge) between two switch "ears";
>   encoder sits at the bay bottom with the wheel hanging into it
> - chamfered corners, mid-side steps, **narrowed tail** with the **USB-C charge port at the tail edge**
> - sensor **aperture + LED cutouts** (inside the U5 footprint, per PixArt Table 9); optical center (135, 106)
> - **3× M3 mounting holes** (board-only footprints MH1–MH3); antenna in a copper-free tail zone
> - geometric containment check: every pad verified inside the shaped outline
>
> **Full electrical audit (v4):** every pad on the PCB was machine-compared against the
> schematic netlist — 309 pads vs 298 assignments (250 named nets + 48 no-connects),
> **0 mismatches**; die pad→GND, USB shield→GND, crystal shell→GND, antenna stub→GND
> verified as the only intentional board-side extras. Schematic ERC = 0, PCB DRC = 0 errors.

nRF52833 (integrated 2.4 GHz radio) · PixArt PAW3311DB (datasheet-verified wiring) ·
4× Kailh GM 8.0 · scroll encoder · BQ24074 charger · **single 1.9 V system rail**.

## Contents

| File | What |
|---|---|
| `hakai_mouse_rev2.kicad_pro` | Project file — open this in KiCad 8/9/10 |
| `hakai_mouse_rev2.kicad_sch` | Schematic. ERC = 0. Netlist machine-verified against the design doc (44 nets) |
| `hakai_mouse_rev2.kicad_pcb` | Board: all 91 footprints placed + full net assignment. **UNROUTED** (see below). DRC = 0 errors (silk warnings only) |
| `hakai_mouse_rev2.pdf` | Plotted schematic |
| `BOM_hakai_mouse_rev2.csv` | Grouped bill of materials (kicad-cli export) |
| `Cost_Estimate_hakai_mouse_rev2.csv` | Per-part approximate prototype costs + PCB fab + totals |
| `footprints.pretty/` + `fp-lib-table` | Custom footprints: PAW3311 iDIP-8 (with aperture/LED board cutouts per datasheet Table 9), Kailh GM8/D2F, 11 mm encoder |
| `datasheets/PAW3311DB-T2MU_v1.0.pdf` | PixArt datasheet (source of all sensor wiring) |

## Board facts

- 70 × 110 mm, **0.8 mm thickness** (PAW3311 lens stack requires it), 2-layer.
- Sensor optical center at board center; sensor aperture + LED **board cutouts** are on Edge.Cuts inside the sensor footprint.
- GND pour on both layers, shaped to keep the antenna region copper-free.
- Antenna: TI SWRA117D PCB IFA (proven 2.4 GHz copper footprint from the KiCad library).

## Before fab — the honest list

1. **Route it.** The board is placed + netted, not routed. RF path (nRF ANT → C22/L3/C23/L4 → ANT1):
   copy the trace/ground geometry from Nordic's PCA10100 reference, 50 Ω, shunt caps grounded to the
   VSS nearest ANT, stitch vias around the RF section. Then VNA-tune C24.
2. **Enlarge the LED cutout** in the sensor footprint from the DRC-safe R0.65 circle to the datasheet's
   R0.90 × 2.00 stadium, and use the lens datasheet's LED pad geometry (a generic 1206 is close but not exact).
3. **Verify the encoder footprint** against your actual vendor (TTC/Alps/F-switch pin spacing varies).
4. Kailh switch footprint: add the two locating-boss holes per the Omron D2F drawing.
5. JST battery pigtail: **verify polarity with a DMM** — pin 1 = BAT+ is this design's convention, there is no JST standard.
6. SWD probe VTref = 1.9 V logic.

## Firmware bring-up notes

- SPI mode 3, ≤2 MHz initially (R23 = 3.3 k matches 2 MHz; 1 k @ 4 MHz, 240 Ω @ 8 MHz).
- 3-wire SDIO bridge: MCU MISO reads SDIO directly; MOSI drives through R23.
- Wake-from-shutdown requires RESET, then 50 ms before valid motion (tMOT-RST).
- nRESET is P0.18 via UICR PSELRESET; DC/DC REG1 enabled (10 µH + 15 nH fitted).

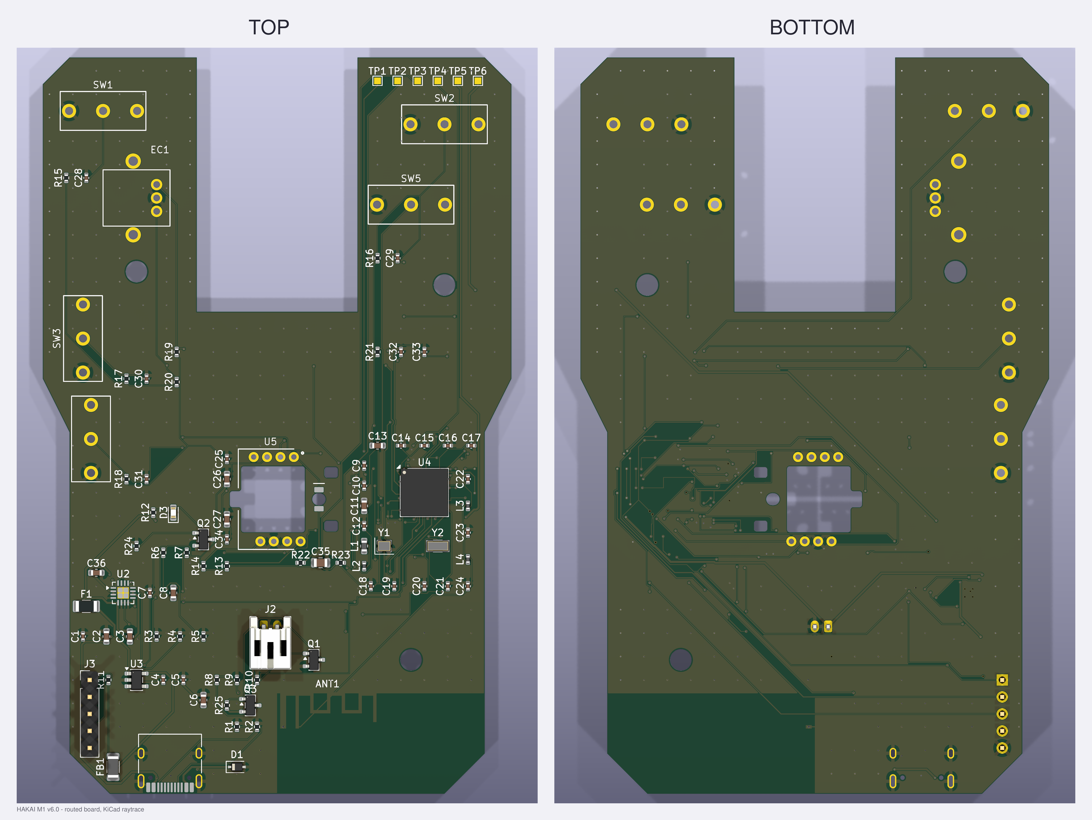
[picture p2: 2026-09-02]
hardware/v6-final-v2/board_render_both_sides.png

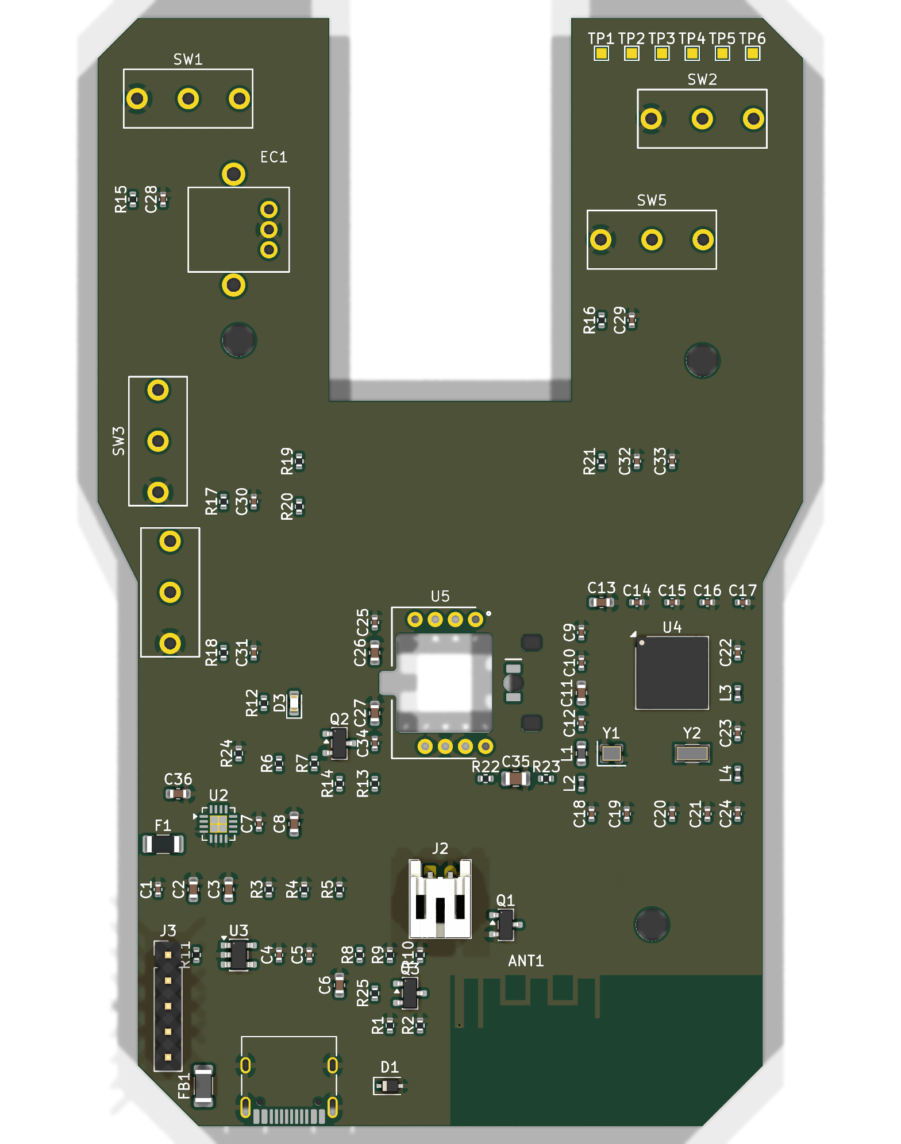
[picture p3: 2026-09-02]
hardware/final/board_top_render.png

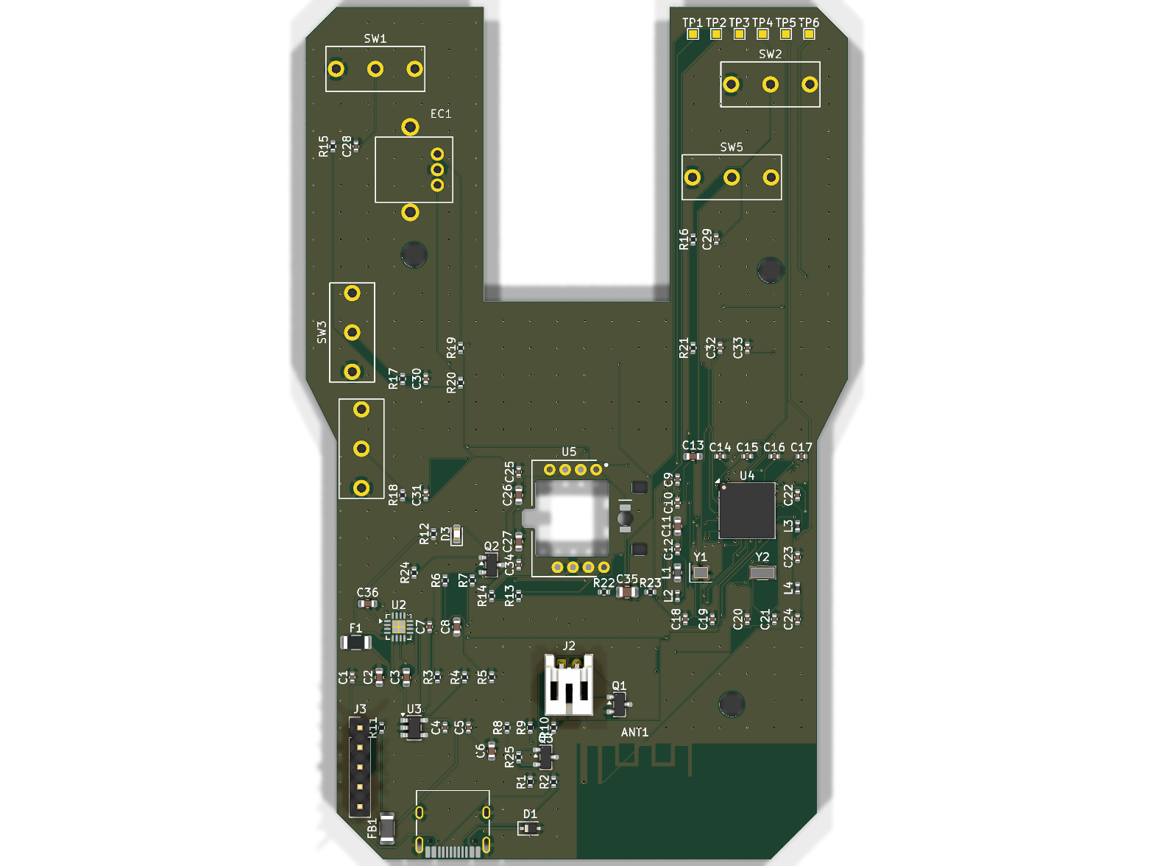
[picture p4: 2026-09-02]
hardware/v6-final-v2/board_top_render.png

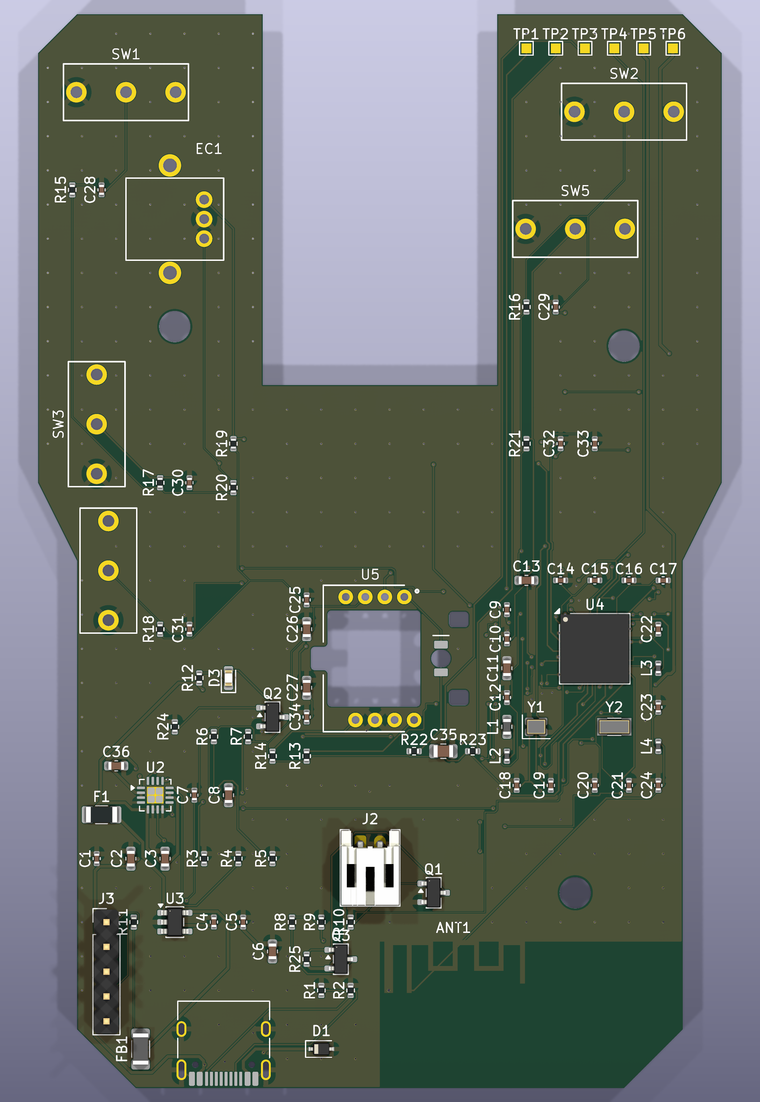
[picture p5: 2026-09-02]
hardware/v6-final-v2/board_render_top.png

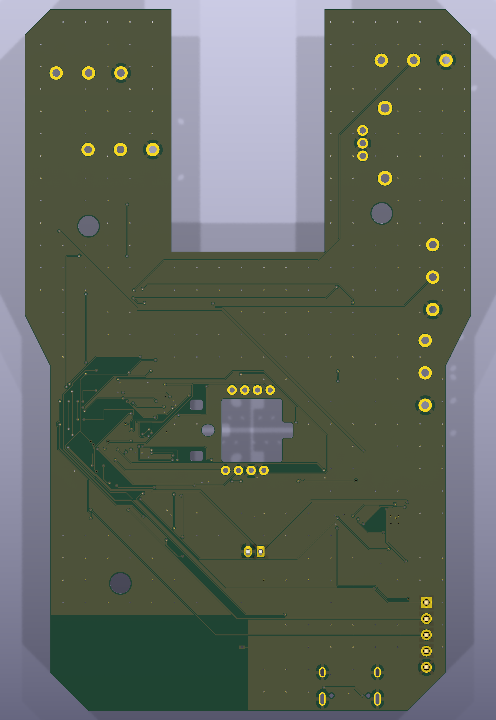
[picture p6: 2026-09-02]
hardware/v6-final-v2/board_render_bottom.png

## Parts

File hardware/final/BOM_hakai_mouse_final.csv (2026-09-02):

Refs | Value | Footprint | Qty | DNP
ANT1 | PCB IFA 2.4GHz | RF_Antenna:Texas_SWRA117D_2.4GHz_Right | 1
C1,C4,C5,C14 | 1uF | Capacitor_SMD:C_0402_1005Metric | 4
C2,C3,C6,C8,C26,C36 | 10uF | Capacitor_SMD:C_0603_1608Metric | 6
C7,C9,C15-C17,C25,C34 | 100nF | Capacitor_SMD:C_0402_1005Metric | 7
C10 | 100pF NP0 | Capacitor_SMD:C_0402_1005Metric | 1
C11 | 1uF | Capacitor_SMD:C_0603_1608Metric | 1
C12 | 47nF | Capacitor_SMD:C_0402_1005Metric | 1
C13 | 4.7uF | Capacitor_SMD:C_0603_1608Metric | 1
C18-C21 | 12pF NP0 | Capacitor_SMD:C_0402_1005Metric | 4
C22 | 1.0pF NP0 | Capacitor_SMD:C_0402_1005Metric | 1
C23 | 1.2pF NP0 | Capacitor_SMD:C_0402_1005Metric | 1
C24 | 1.2pF (DNP) | Capacitor_SMD:C_0402_1005Metric | 1 | DNP
C27 | 4.7uF/10V | Capacitor_SMD:C_0603_1608Metric | 1
C28-C31 | 100nF (DNP) | Capacitor_SMD:C_0402_1005Metric | 4 | DNP
C32,C33 | 10nF | Capacitor_SMD:C_0402_1005Metric | 2
C35 | 33uF | Capacitor_SMD:C_0805_2012Metric | 1
D1 | PESD5V0S1BA | Diode_SMD:D_SOD-323 | 1
D2 | IR LED (SMT / L0AJ-LSG1 set) | hakai_fp:IRLED_L0AJ_3311 | 1
D3 | BLUE | LED_SMD:LED_0603_1608Metric | 1
EC1 | 11mm encoder | hakai_fp:ENC_Mouse_11mm | 1
F1 | PTC 1A | Fuse:Fuse_1206_3216Metric | 1
FB1 | 600R@100MHz | Inductor_SMD:L_1206_3216Metric | 1
J1 | USB4105-GF-A | Connector_USB:USB_C_Receptacle_HRO_TYPE-C-31-M-12 | 1
J2 | JST S2B-PH-K | Connector_JST:JST_PH_S2B-PH-K_1x02_P2.00mm_Horizontal | 1
J3 | SWD 1x05 | Connector_PinHeader_2.54mm:PinHeader_1x05_P2.54mm_Vertical | 1
L1 | 10uH | Inductor_SMD:L_0603_1608Metric | 1
L2 | 15nH | Inductor_SMD:L_0402_1005Metric | 1
L3 | 4.7nH | Inductor_SMD:L_0402_1005Metric | 1
L4 | 2.2nH | Inductor_SMD:L_0402_1005Metric | 1
Q1,Q2 | AO3400A | Package_TO_SOT_SMD:SOT-23 | 2
Q3 | AO3401A | Package_TO_SOT_SMD:SOT-23 | 1
R1,R2 | 5.1k | Resistor_SMD:R_0402_1005Metric | 2
R3,R11,R13,R15-R21 | 10k | Resistor_SMD:R_0402_1005Metric | 10
R4 | 3.24k | Resistor_SMD:R_0402_1005Metric | 1
R5 | 2.0k | Resistor_SMD:R_0402_1005Metric | 1
R6,R7,R9,R10,R24 | 100k | Resistor_SMD:R_0402_1005Metric | 5
R8 | 200k | Resistor_SMD:R_0402_1005Metric | 1
R12 | 1k | Resistor_SMD:R_0402_1005Metric | 1
R14 | 10k (DNP) | Resistor_SMD:R_0402_1005Metric | 1 | DNP
R22 | 18R 1% | Resistor_SMD:R_0402_1005Metric | 1
R23 | 3.3k 1% | Resistor_SMD:R_0402_1005Metric | 1
R25 | 47k | Resistor_SMD:R_0402_1005Metric | 1
SW1-SW5 | Kailh GM 8.0 | hakai_fp:SW_Kailh_GM8_D2F | 5
TP1 | TP1 | TestPoint:TestPoint_Pad_1.0x1.0mm | 1
TP2 | TP2 | TestPoint:TestPoint_Pad_1.0x1.0mm | 1
TP3 | TP3 | TestPoint:TestPoint_Pad_1.0x1.0mm | 1
TP4 | TP4 | TestPoint:TestPoint_Pad_1.0x1.0mm | 1
TP5 | TP5 | TestPoint:TestPoint_Pad_1.0x1.0mm | 1
TP6 | TP6 | TestPoint:TestPoint_Pad_1.0x1.0mm | 1
U2 | BQ24074 | Package_DFN_QFN:VQFN-16-1EP_3x3mm_P0.5mm_EP1.68x1.68mm_ThermalVias | 1
U3 | XC6219B192MR | Package_TO_SOT_SMD:SOT-23-5 | 1
U4 | nRF52833-QIAA (Bxx+) | Package_DFN_QFN:Nordic_AQFN-73-1EP_7x7mm_P0.5mm | 1
U5 | PAW3311DB-T2MU | hakai_fp:PAW3311DB_iDIP8_L0AJ | 1
Y1 | 32MHz CL=8pF | Crystal:Crystal_SMD_2016-4Pin_2.0x1.6mm | 1
Y2 | 32.768kHz CL=9pF | Crystal:Crystal_SMD_3215-2Pin_3.2x1.5mm | 1

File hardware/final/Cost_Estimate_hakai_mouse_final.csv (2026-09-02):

Category | Ref(s) | Part / Description | Qty | Unit Cost USD (est) | Extended USD | Sourcing note
IC | U4 | Nordic nRF52833-QIAA aQFN73 (MCU + 2.4GHz radio) | 1 | 4.50 | 4.50 | LCSC/Mouser ~$3.8-5.5 @ qty1; cheaper in reels
IC | U5 | PixArt PAW3311DB-T2MU optical sensor | 1 | 4.00 | 4.00 | LCSC C9900151010 / AliExpress (Duoyi) ~$3-6; via PixArt distributor (EPSGlobal) for volume
Optics | - | L0AJ-LSG1 SMT lens (pairs with U5) | 1 | 1.20 | 1.20 | From PixArt distributor with sensor; 5mm lens sets (LM31-LNG) similar
IC | U2 | TI BQ24074RGT Li-ion charger + power path | 1 | 1.80 | 1.80 | TI.com/Mouser ~$1.5-2.5 @ qty1
IC | U3 | Torex XC6219B192MR 1.9V 240mA LDO | 1 | 0.35 | 0.35 | LCSC/Digi-Key ~$0.25-0.50
Connector | J1 | GCT USB4105-GF-A USB-C 16-pin receptacle | 1 | 0.60 | 0.60 | LCSC (HRO TYPE-C-31-M-12 equivalent ~$0.15-0.30)
Switch | SW1-SW5 | Kailh GM 8.0 mouse microswitch (80M) - L/R/side x2/middle click | 5 | 0.65 | 3.25 | One part number for every click; GM 4.0 (~$0.30) is a lighter/cheaper SW5 option
Encoder | EC1 | 11mm mouse scroll encoder - rotation only (TTC/F-switch) | 1 | 0.25 | 0.25 | AliExpress/LCSC ~$0.10-0.30; verify pin/bracket spacing vs vendor drawing
LED | D2 | SMT IR emitter for L0AJ-LSG1 set (1206) | 1 | 0.30 | 0.30 | Per PixArt recommendation (contact PixArt for exact P/N)
Crystal | Y1 | 32MHz 2016 CL=8pF (Nordic-approved list) | 1 | 0.35 | 0.35 | e.g. NDK NX2016SA / Epson FA-238 class
Crystal | Y2 | 32.768kHz 3215 CL=9pF | 1 | 0.25 | 0.25 | e.g. Epson FC-135 class
FET | Q1-Q2 | AO3400A N-MOSFET SOT-23 (low Vth) | 2 | 0.04 | 0.08 | LCSC ~$0.02-0.05
FET | Q3 | AO3401A P-MOSFET SOT-23 (v5.2 high-side battery-divider switch) | 1 | 0.05 | 0.05 | LCSC ~$0.02-0.06
TVS | D1 | PESD5V0S1BA SOD-323 (VBUS ESD) | 1 | 0.06 | 0.06 | Nexperia; any 5V bidirectional TVS works
LED | D3 | Status LED blue 0603 | 1 | 0.04 | 0.04 | Any 0603 LED (driven from VSYS via Q2)
Protection | F1 | PTC resettable fuse 1A hold 1206 | 1 | 0.10 | 0.10 | Bourns MF-MSMF/Techfuse
Filter | FB1 | Murata BLM31PG601SN1L ferrite 600R@100MHz 1206 | 1 | 0.08 | 0.08 | Or any 1206 600R bead rated >=0.5A
Inductor | L1 | 10uH 0603 chip inductor (DC/DC; IDC>=50mA) | 1 | 0.06 | 0.06 | Per Nordic reference BOM
Inductor | L2 | 15nH 0402 high-freq chip inductor (DC/DC) | 1 | 0.03 | 0.03 | Per Nordic reference BOM
Inductor | L3 | 4.7nH 0402 Murata LQG15HS4N7 (RF match) | 1 | 0.04 | 0.04 | Copy Nordic reference exactly - do not substitute casually
Inductor | L4 | 2.2nH 0402 Murata LQG15HS2N2 (RF match) | 1 | 0.04 | 0.04 | Copy Nordic reference exactly
Connector | J2 | JST S2B-PH-K-S 2-pin battery header | 1 | 0.12 | 0.12 | Verify pack pigtail polarity before connecting!
Connector | J3 | Pin header 1x05 2.54mm (SWD debug) | 1 | 0.05 | 0.05 | Can be left unpopulated in production
Resistor | R1-R25 (24 fitted + 1 DNP) | 0402 1% assorted (5.1k/10k/47k/100k/200k/3.24k/2.0k/1k/18R/3.3k) | 25 | 0.01 | 0.25 | LCSC reels; 18R and 3.24k must be 1%; R25 = 47k (v5.3)
Capacitor | C1-C36 (31 fitted + 5 DNP) | 0402/0603/0805 assorted (see BOM; NP0 for RF/12pF/100pF) | 36 | 0.015 | 0.54 | NP0/C0G mandatory for C10 C18-C24; X7R elsewhere
Test point | TP1-TP6 | Copper pad test points | 6 | 0.00 | 0.00 | Bare copper - no part cost
PCB | - | PCB fabrication 70x110mm, 2-layer, 0.8mm (sensor requires 0.8mm), qty 5 | 1 | 7.00 | 7.00 | JLCPCB/PCBWay ~$4-10 for 5 pcs incl. shipping share; 4-layer (better RF) ~$25/5
PCB | - | Solder stencil (optional but recommended for aQFN73) | 1 | 8.00 | 8.00 | Frameless stencil
Off-board | - | Li-ion cell 503035/603040 ~500-800mAh, protected, JST-PH pigtail | 1 | 3.50 | 3.50 | NOT on PCB BOM; verify polarity vs J2 pin 1 = BAT+
TOTAL |  | PCB components only (one board) |  |  | 18.39 | Sum of all part rows above - R/C quantities include DNP reel stock (fitted-only ~$18.31). v5.2: +C36 +Q3/R25 = +$0.07
TOTAL |  | One assembled prototype (components + PCB share + stencil share) |  |  | 21.39 | Assumes 5-board run; stencil+fab amortized over 5
TOTAL |  | Complete unit incl. battery |  |  | 24.89 | Shell/feet/cable not included
NOTE |  | All prices are qty-1..10 prototype ESTIMATES (2026 USD, LCSC/Mouser/AliExpress mix). Volume pricing (1k+) typically drops total component cost below $9.
NOTE |  | Verify current prices before ordering: nRF52833 and PAW3311 dominate cost and fluctuate.

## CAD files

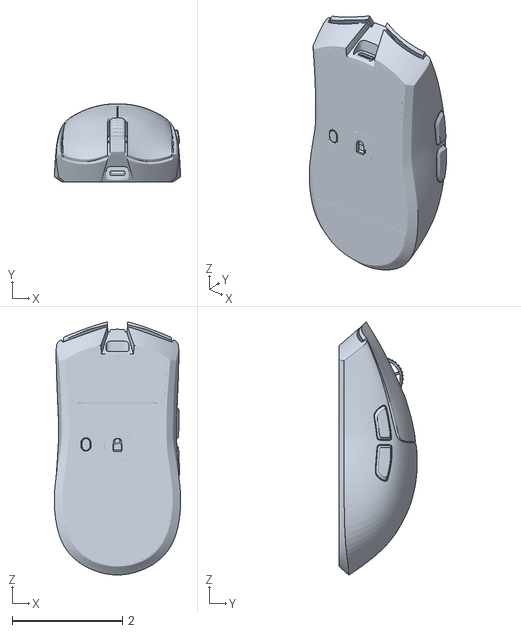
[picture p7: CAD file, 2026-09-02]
site/assets/hakai.obj
2.30 x 1.43 x 4.60

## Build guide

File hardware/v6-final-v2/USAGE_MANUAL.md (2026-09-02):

# HAKAI M1 Wireless Gaming Mouse — v6.0 Usage & Bring-Up Manual

This is the practical companion to `README.md` (release notes) and
`DATASHEET_hakai_mouse_v6.pdf` (product-level specs). Read the README's
**pin-swap** and **hand-fix** sections before doing anything else.

---

## 1. BEFORE ORDERING BOARDS — mandatory checklist

1. **Close the two documented GND hand-fixes** (C12-2 and C19-2 pour tongues)
   in KiCad interactively — see §6. The board must show
   `unconnected = 0` in DRC afterwards. **Do not fab before this.**
2. Order class: **2-layer, 0.8 mm thickness** (non-negotiable — sensor lens
   stack), 1 oz copper. Capability needed: 0.10 mm track / 0.075 mm spacing
   (QFN courtyards only), 0.20 mm min drill, 0.20 mm hole-to-copper.
   That is "advanced" prototype class at JLCPCB/PCBWay — confirm 3.5 mil.
3. Upload `GERBERS_hakai_v6_PROTO.zip` — but ONLY after re-exporting it from
   the hand-fixed board (`bash tools/package_v6.sh` regenerates everything).
4. Solder stencil: order for **F.Paste** (top only; bottom has no parts).

## 2. Sourcing highlights (full list in `BOM_hakai_mouse_v6.csv`)

- U4 nRF52833-QIAA (build code Bxx+), U5 PixArt PAW3311DB-T2MU + **L0AJ-LSG1
  lens set** (SMT IR emitter — confirm D2's pads vs the emitter you buy),
  U2 BQ24074RGTR, U3 XC6219B192MR (1.9 V!).
- 5× Kailh GM 8.0 (SW1–SW5), EC1 = 11 mm rotation-only mouse encoder
  (verify drawing vs the generic footprint), J2 JST PH battery (pin 1 = BAT+
  **this design's convention — verify pigtail with a DMM**), USB-C 16-pin.
- Estimated cost: **$18.39 parts / $21.39 assembled proto / $24.89 w/ battery**
  (`Cost_Estimate_hakai_mouse_v6.csv`).

## 3. Assembly order & notes

1. Reflow top side (single-sided assembly). The nRF EP and BQ24074 EP need
   good paste coverage; the EP ground via at (155.40, 100.05) is intentional.
2. Hand-fit afterwards: SW1–SW5, EC1, J3 header, JST battery lead.
3. **Sensor stack**: fit the L0AJ lens through the two guide-post holes
   (self-aligning, can be heat-staked), PCB thickness 0.8 mm gives the
   2.2–2.6 mm lens-to-surface height. Keep the aperture area clean.
4. Battery: 3.7 V LiPo, **protected cell**, JST PH. Double-check polarity.

## 4. First power-on

1. Bench supply or battery; check 1V9 rail = 1.90 V ±3% (TP row / C5).
2. USB-C in: BQ24074 PGOOD (via nRF P0.15) low, charge LED logic on P0.14;
   charge current set 445 mA, input limit 497 mA.
3. SWD debug on J3 (1×05: 1V9, SWDIO, SWDCLK, nRESET, GND) — **set the
   probe VTref to 1.9 V**; nRESET is P0.18 via UICR PSELRESET.

## 5. Firmware pin map (v6.0 — note the three swaps!)

| Function | Pin | Notes |
|---|---|---|
| BTN_LEFT | P0.04 | active-low, 10 k pull-up |
| **BTN_RIGHT** | **P1.02** | was P0.05 in v5.3 |
| **BTN_SIDE_BACK** | **P1.04** | was P0.06 |
| BTN_SIDE_FWD | P0.07 | |
| ENC_A / ENC_B | P0.08 / P0.11 | nRF QDEC peripheral |
| ENC_SW (middle) | P0.12 | SW5 Kailh |
| SPI SCK / MOSI / MISO | P0.20 / P0.22 / P0.24 | 3-wire SDIO bridge (R23 3.3 k), mode 3, start ≤2 MHz |
| SENS_NCS / MOTION | P0.17 / P0.19 | MOTION push-pull active-low |
| LED_STAT | P0.13 | drives Q2 from VSYS (blue LED) |
| STAT / PGOOD | P0.14 / P0.15 | charger status, active-low |
| **VBAT_EN** | **P1.00** | was P0.03. Drive HIGH to sample battery |
| VBAT_SENSE | P0.02 / AIN0 | VBAT ÷3 (200 k/100 k), ~103 µA only while sampling |

Sensor wake-from-shutdown needs RESET + 50 ms (t_MOT-RST). DC/DC is fitted
(L1/L2) — enable REG1 DC/DC in firmware for radio efficiency.

## 6. The two hand-fixes (do these first — ~5 min each in KiCad)

Open `hakai_mouse_v6.kicad_pcb`, run DRC — you'll see 2 unconnected items:

- **C12-2** (47 nF, DEC4_6 bypass, near x=148, y=109.5): the GND tongue is
  boxed in by STAT's B.Cu horizontal (y≈108.6) and BTN_SIDE_BACK's pair
  (y≈109.10/109.55). Push-shove (hotkey `X`, walk into the STAT track) the
  STAT run ~0.4 mm north OR the BS-BACK pair south, then drop a GND via
  (0.45/0.20) in the freed band and let the zones refill.
- **C19-2** (12 pF, XC2 crystal load, near x=152.5, y=118.5): an XL2-area
  B.Cu diagonal crosses under the pad. Shove it ~0.3 mm SW and drop a GND
  via in the tongue, or drag a 0.15 mm GND track from the pad south-east to
  the via at (153.5, 122.5).

Refill zones (`B`), re-run DRC → expect **unconnected 0, errors 0** (4 silk
warnings are known-cosmetic). Then re-export fab files:
`bash tools/package_v6.sh`.

## 7. RF / antenna

The 2.4 GHz IFA and its feed keep Nordic's PCA10100 geometry; the tail zone
is copper-free on both layers. After assembly, measure with a VNA and fit
**C24** (DNP placeholder) to tune; typical starting value 1.2 pF.

## 8. Regenerating anything

All tools run with KiCad 10's bundled Python
(`"C:\Program Files\KiCad\10.0\bin\python.exe"`), paths package-relative:

```
python tools/gen_kicad.py            # schematic (rev 6.0, pin swaps included)
kicad-cli sch export netlist --output build/net.net hakai_mouse_v6.kicad_sch
python tools/check_netlist.py        # netlist vs design intent (45+6 nets)
python tools/pcb_check.py            # pad-by-pad audit vs netlist
python tools/verify_pkg.py           # containment/BOM/cost/inventory
bash   tools/package_v6.sh           # gerbers + drill + zip + render + reports
```

Routing archaeology (Freerouting jar, DSN/SES flow, repair scripts) is in
`tools/` — see README §"How it was routed".

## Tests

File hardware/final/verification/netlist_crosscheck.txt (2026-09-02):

ALL CHECKS PASS: 45 signal nets exact-match, 6 rails verified, 100 total nets in netlist

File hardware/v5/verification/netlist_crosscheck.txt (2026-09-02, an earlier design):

ALL CHECKS PASS: 44 signal nets exact-match, 6 rails verified, 99 total nets in netlist

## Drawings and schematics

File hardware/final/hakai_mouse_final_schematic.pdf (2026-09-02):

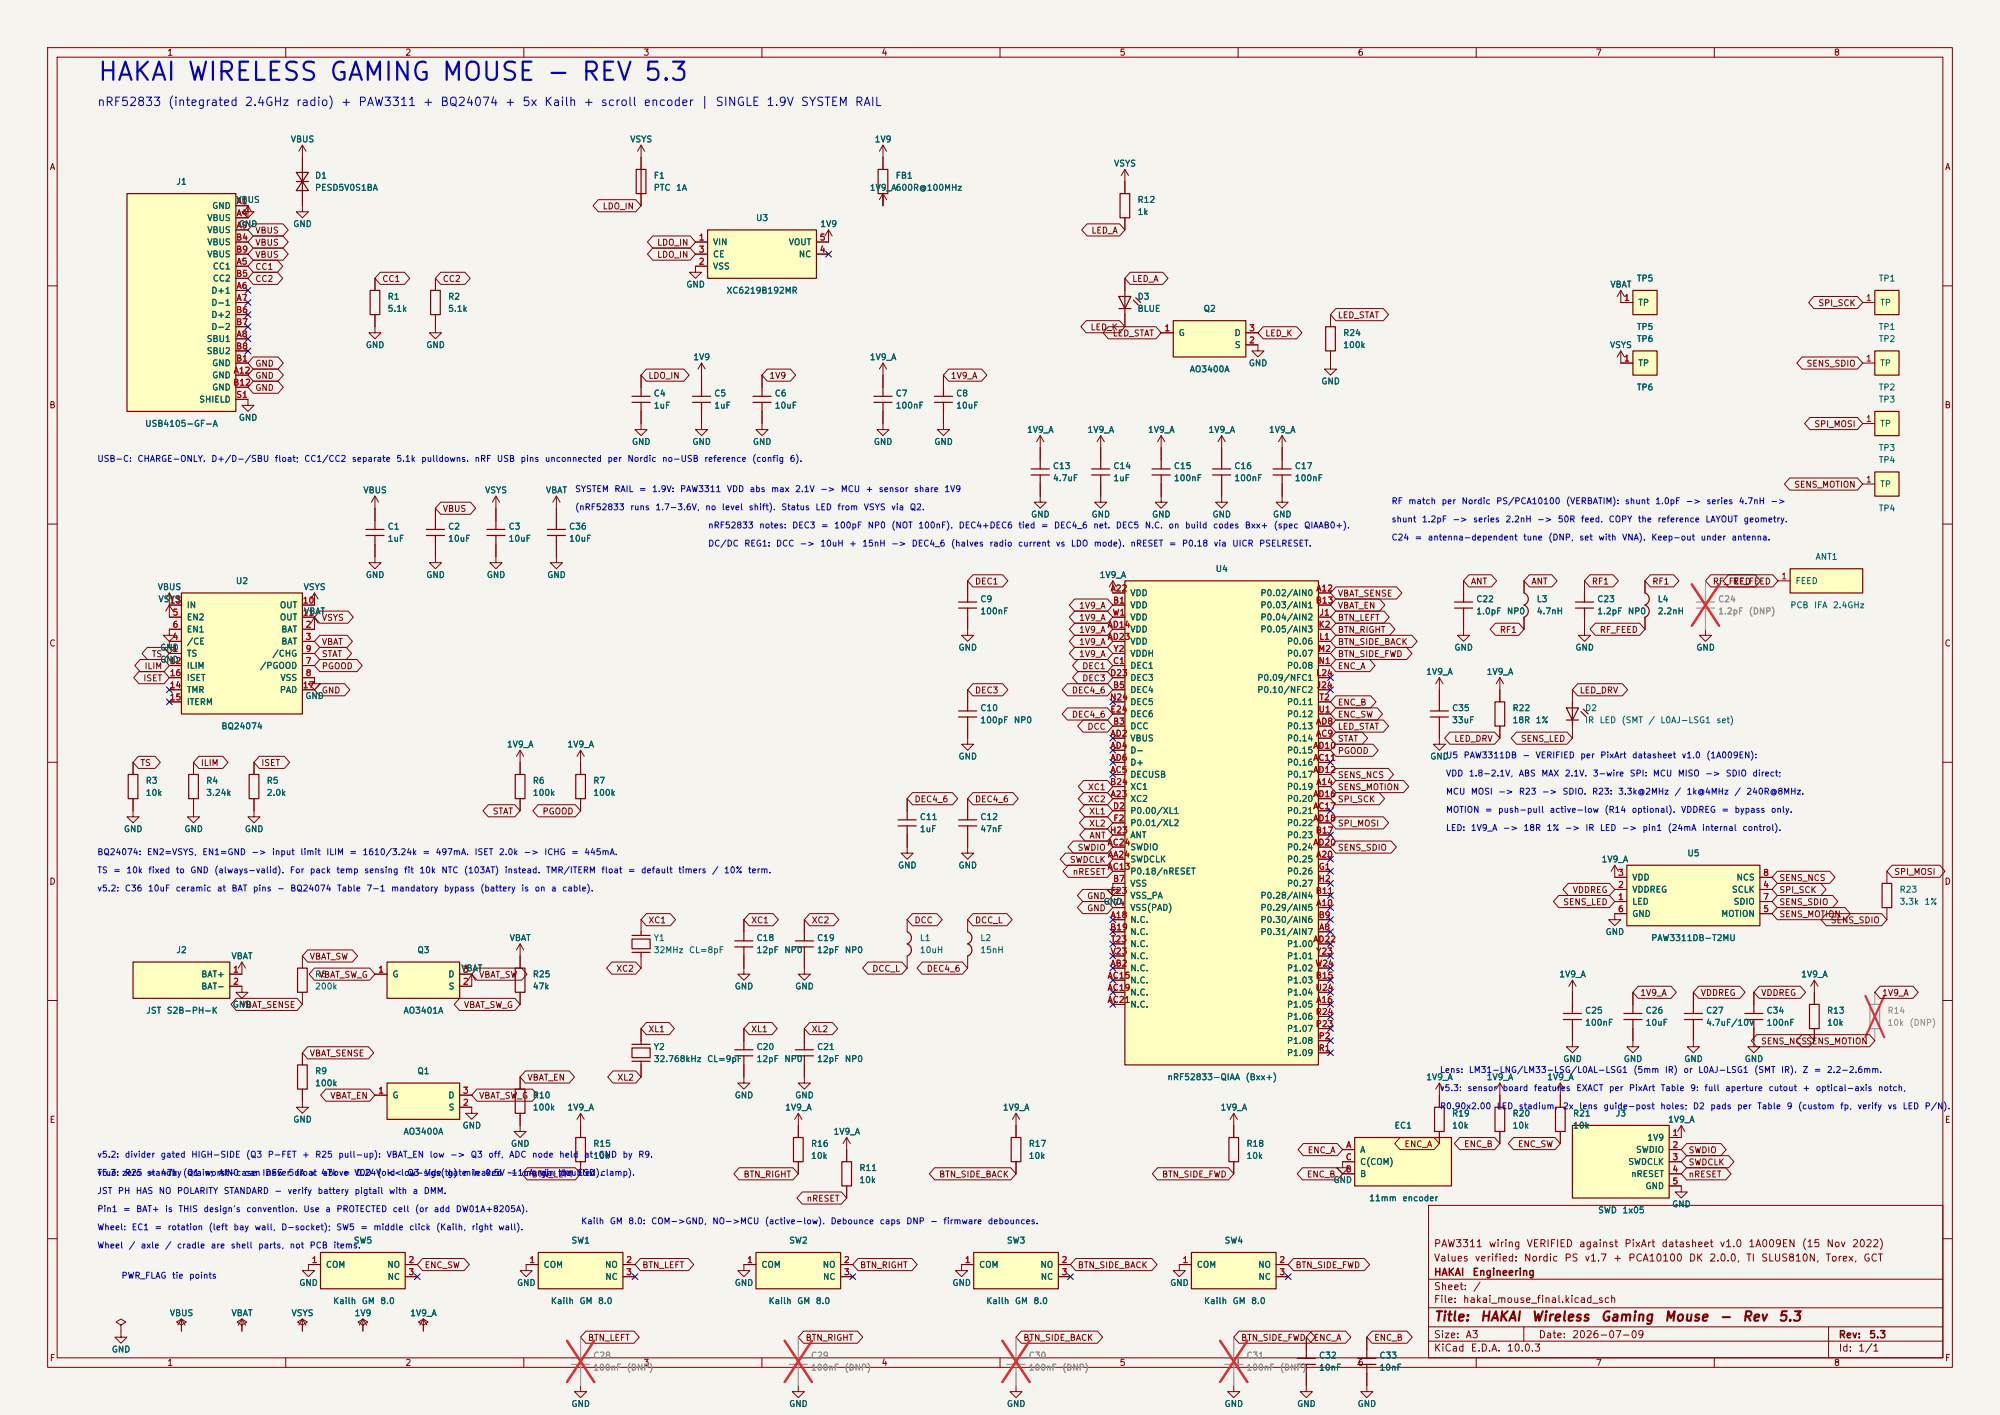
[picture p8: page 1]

HAKAI WIRELESS GAMING MOUSE - REV 5.3
J1 USB4105-GF-A

nRF52833 (integrated 2.4GHz radio) + PAW3311 + BQ24074 + 5x Kailh + scroll encoder | SINGLE 1.9V SYSTEM RAIL

USB-C: CHARGE-ONLY. D+/D-/SBU float; CC1/CC2 separate 5.1k pulldowns. nRF USB pins unconnected per Nordic no-USB reference (config 6).

(nRF52833 runs 1.7-3.6V, no level shift). Status LED from VSYS via Q2. SYSTEM RAIL = 1.9V: PAW3311 VDD abs max 2.1V -> MCU + sensor share 1V9

RF match per Nordic PS/PCA10100 (VERBATIM): shunt 1.0pF -> series 4.7nH ->

nRF52833 notes: DEC3 = 100pF NP0 (NOT 100nF). DEC4+DEC6 tied = DEC4_6 net. DEC5 N.C. on build codes Bxx+ (spec QIAAB0+).

True zero standby drain; AIN0 can never float above VDD (old low-side gate leaked ~11uA via the ESD clamp). TS = 10k fixed to GND (always-valid). For pack temp sensing fit 10k NTC (103AT) instead. TMR/ITERM float = default timers / 10% term. DC/DC REG1: DCC -> 10uH + 15nH -> DEC4_6 (halves radio current vs LDO mode). nRESET = P0.18 via UICR PSELRESET.

C24 = antenna-dependent tune (DNP, set with VNA). Keep-out under antenna.

IR LED (SMT / L0AJ-LSG1 set) GND

v5.2: C36 10uF ceramic at BAT pins - BQ24074 Table 7-1 mandatory bypass (battery is on a cable).

SENS_MOTION Wheel / axle / cradle are shell parts, not PCB items.

PAW3311 wiring VERIFIED against PixArt datasheet v1.0 1A009EN (15 Nov 2022) R9

Lens: LM31-LNG/LM33-LSG/L0AL-LSG1 (5mm IR) or L0AJ-LSG1 (SMT IR). Z = 2.2-2.6mm.

v5.3: R25 = 47k (Q1 worst-case IDSS 5uA x 47k = 0.24V << Q3 Vgs(th) min 0.5V - margin doubled).

Values verified: Nordic PS v1.7 + PCA10100 DK 2.0.0, TI SLUS810N, Torex, GCT
HAKAI Engineering
Sheet: /
File: hakai_mouse_final.kicad_sch
Title: HAKAI Wireless Gaming Mouse - Rev 5.3

Size: A3 | Rev: 5.3
KiCad E.D.A. 10.0.3 | Id: 1/1 | F Date: 2026-07-09

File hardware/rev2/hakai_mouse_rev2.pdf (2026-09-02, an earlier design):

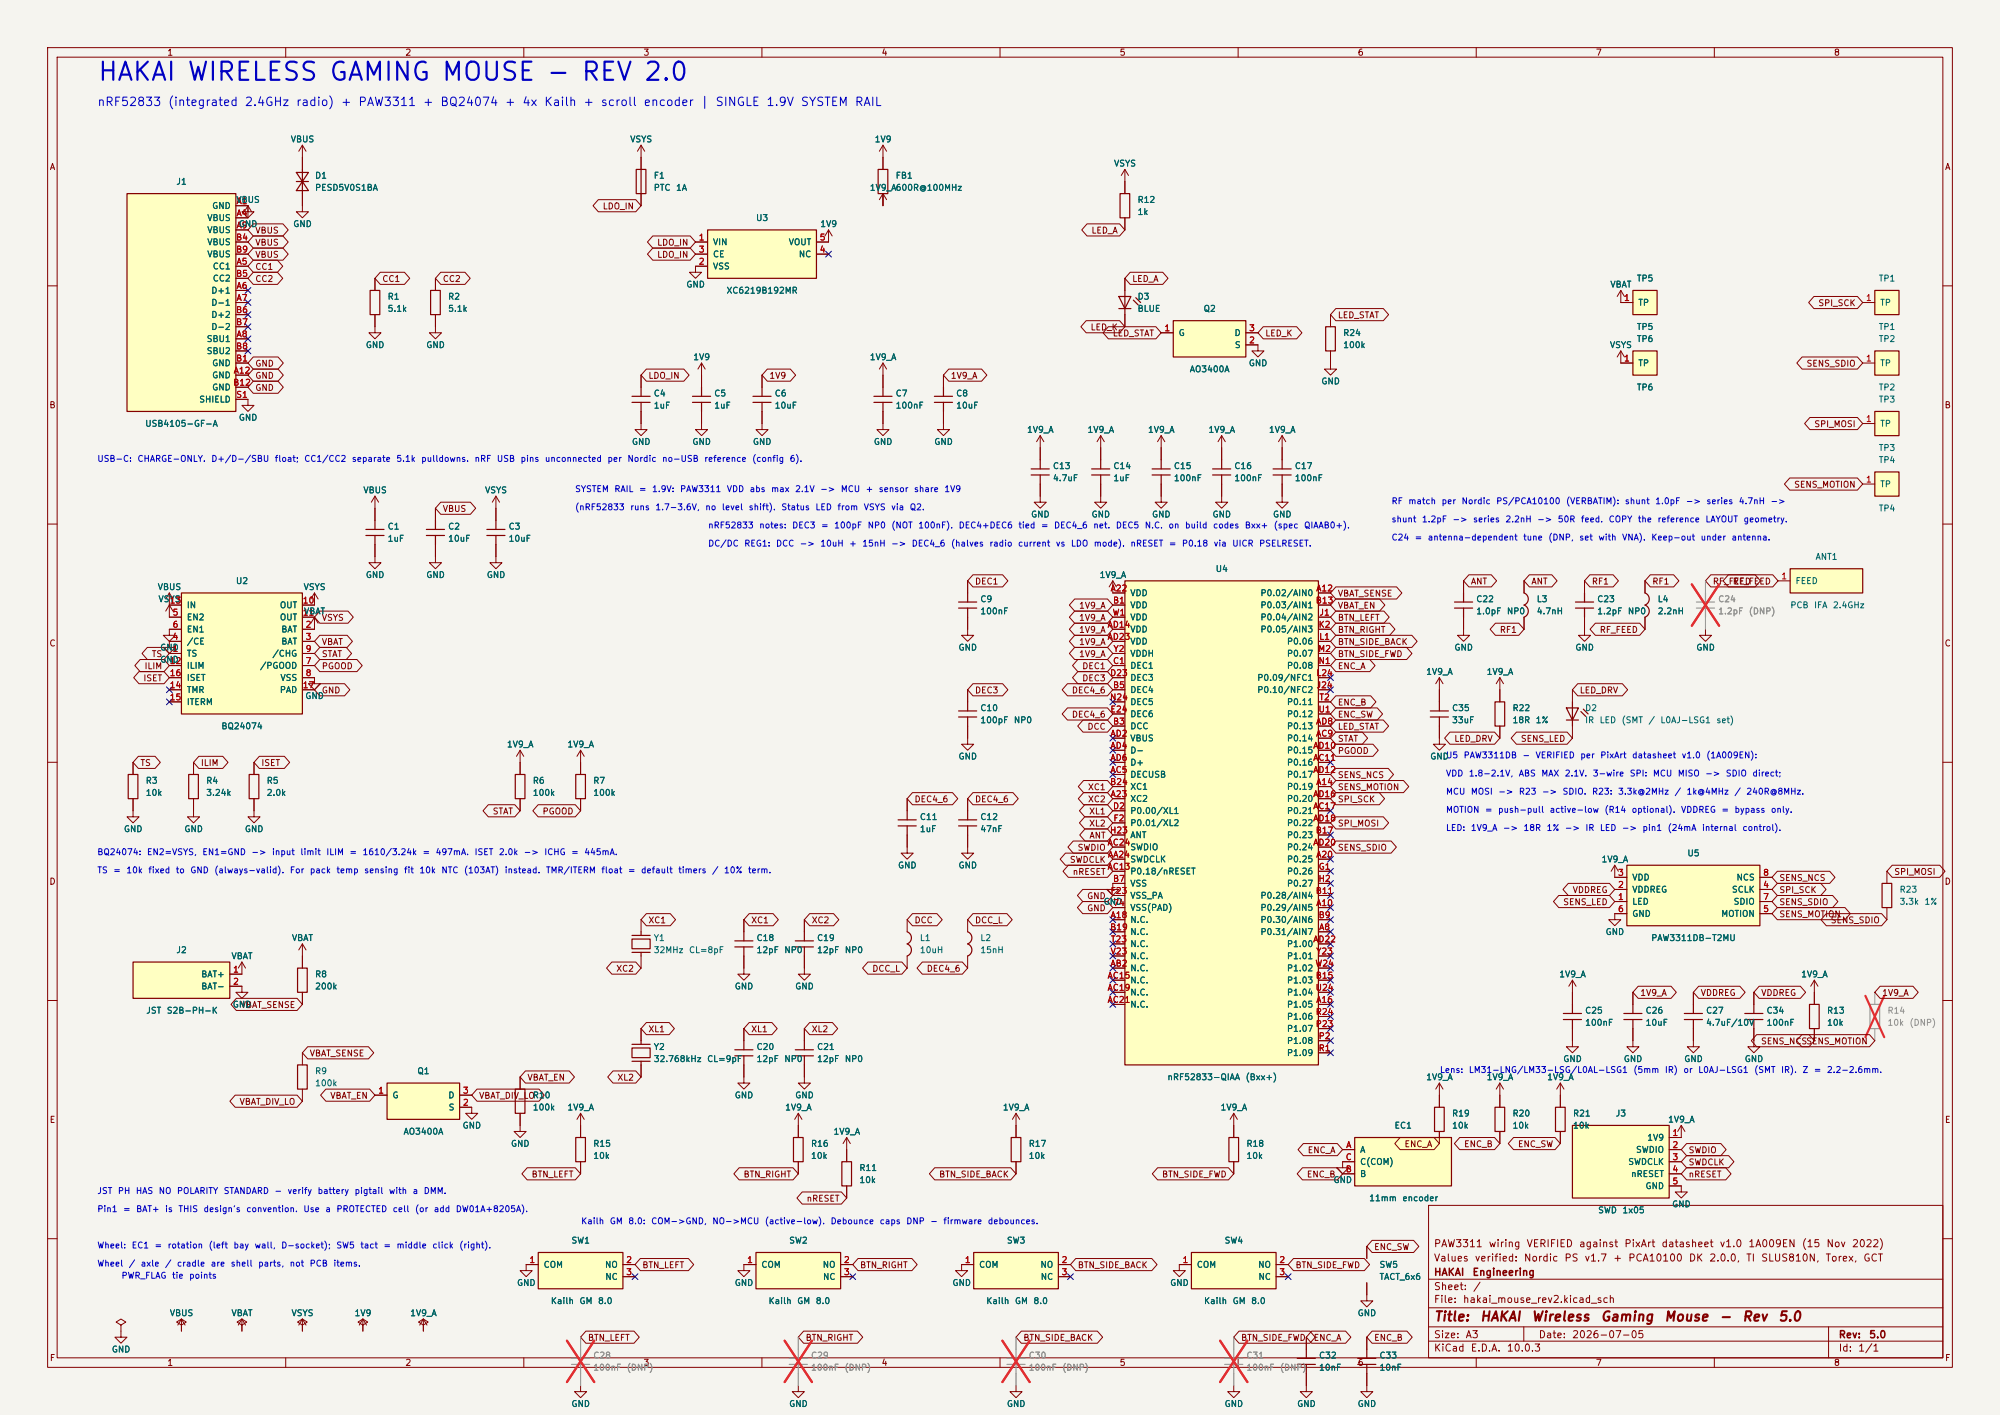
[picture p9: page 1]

HAKAI WIRELESS GAMING MOUSE - REV 2.0

nRF52833 (integrated 2.4GHz radio) + PAW3311 + BQ24074 + 4x Kailh + scroll encoder | SINGLE 1.9V SYSTEM RAIL

USB-C: CHARGE-ONLY. D+/D-/SBU float; CC1/CC2 separate 5.1k pulldowns. nRF USB pins unconnected per Nordic no-USB reference (config 6). nRF52833 notes: DEC3 = 100pF NP0 (NOT 100nF). DEC4+DEC6 tied = DEC4_6 net. DEC5 N.C. on build codes Bxx+ (spec QIAAB0+).

IR LED (SMT / L0AJ-LSG1 set) C15

VDD 1.8-2.1V, ABS MAX 2.1V. 3-wire SPI: MCU MISO -> SDIO direct; C24 = antenna-dependent tune (DNP, set with VNA). Keep-out under antenna. SYSTEM RAIL = 1.9V: PAW3311 VDD abs max 2.1V -> MCU + sensor share 1V9
(nRF52833 runs 1.7-3.6V, no level shift). Status LED from VSYS via Q2.

LED: 1V9_A -> 18R 1% -> IR LED -> pin1 (24mA internal control). MCU MOSI -> R23 -> SDIO. R23: 3.3k@2MHz / 1k@4MHz / 240R@8MHz. J3

BQ24074: EN2=VSYS, EN1=GND -> input limit ILIM = 1610/3.24k = 497mA. ISET 2.0k -> ICHG = 445mA. Wheel / axle / cradle are shell parts, not PCB items. Wheel: EC1 = rotation (left bay wall, D-socket); SW5 tact = middle click (right).

Lens: LM31-LNG/LM33-LSG/L0AL-LSG1 (5mm IR) or L0AJ-LSG1 (SMT IR). Z = 2.2-2.6mm. Kailh GM 8.0: COM->GND, NO->MCU (active-low). Debounce caps DNP - firmware debounces. PWR_FLAG tie points

JST PH HAS NO POLARITY STANDARD - verify battery pigtail with a DMM. Pin1 = BAT+ is THIS design's convention. Use a PROTECTED cell (or add DW01A+8205A).

PAW3311 wiring VERIFIED against PixArt datasheet v1.0 1A009EN (15 Nov 2022)
Values verified: Nordic PS v1.7 + PCA10100 DK 2.0.0, TI SLUS810N, Torex, GCT
HAKAI Engineering
Sheet: /
File: hakai_mouse_rev2.kicad_sch
Title: HAKAI Wireless Gaming Mouse - Rev 5.0

Size: A3 | Rev: 5.0
KiCad E.D.A. 10.0.3 | Id: 1/1 | F Date: 2026-07-05

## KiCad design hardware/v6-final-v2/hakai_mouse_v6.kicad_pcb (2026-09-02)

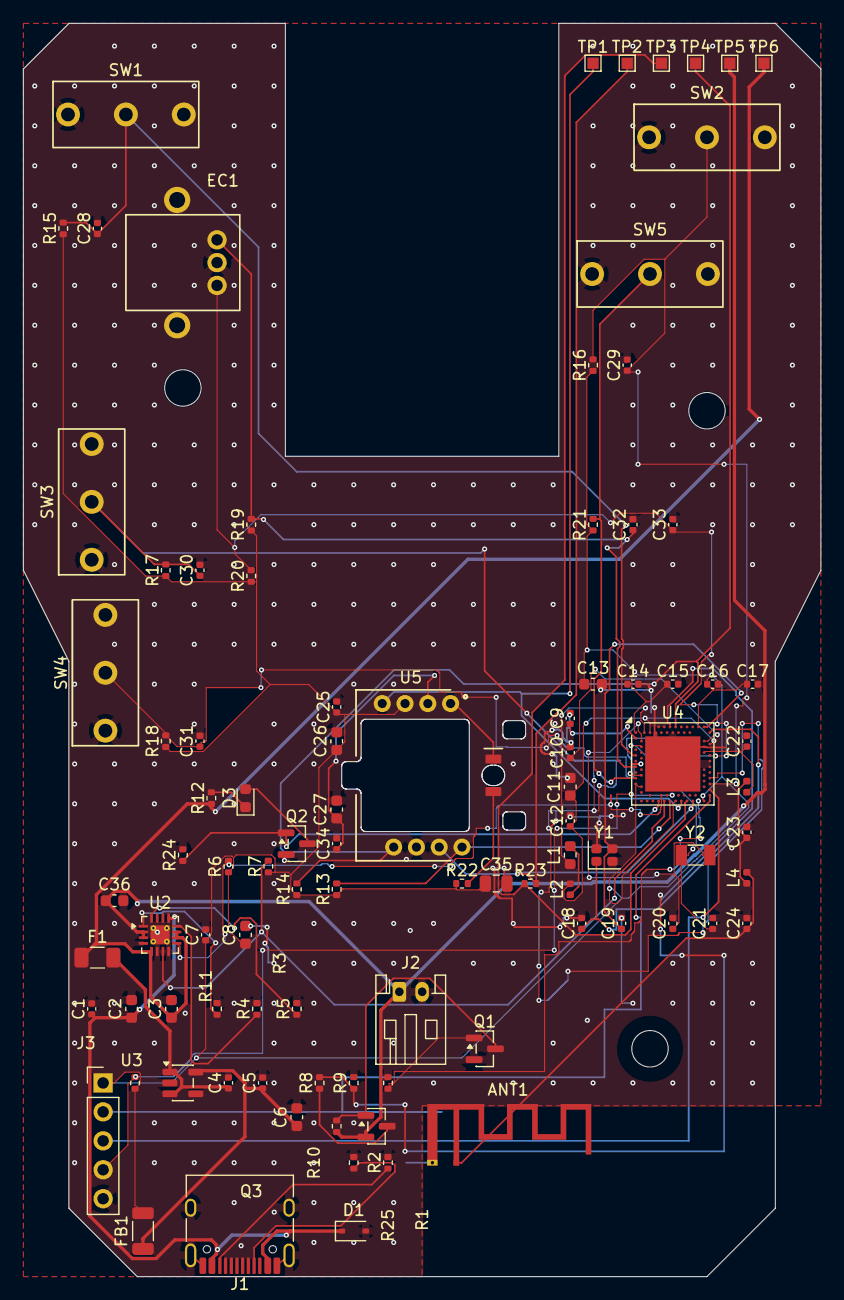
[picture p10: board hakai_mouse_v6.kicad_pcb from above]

Board: 2 copper layers, 70.0 x 110.0 mm, 98 parts (0 on the bottom side), 51 nets.

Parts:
ANT1: PCB IFA 2.4GHz; Texas_SWRA117D_2.4GHz_Right
C1, C4, C5, C14: 1uF; C_0402_1005Metric
C2, C3, C6, C8, C26, C36: 10uF; C_0603_1608Metric
C7, C9, C15, C16, C17, C25, C34: 100nF; C_0402_1005Metric
C10: 100pF NP0; C_0402_1005Metric
C11: 1uF; C_0603_1608Metric
C12: 47nF; C_0402_1005Metric
C13: 4.7uF; C_0603_1608Metric
C18, C19, C20, C21: 12pF NP0; C_0402_1005Metric
C22: 1.0pF NP0; C_0402_1005Metric
C23: 1.2pF NP0; C_0402_1005Metric
C24: 1.2pF (DNP); C_0402_1005Metric
C27: 4.7uF/10V; C_0603_1608Metric
C28, C29, C30, C31: 100nF (DNP); C_0402_1005Metric
C32, C33: 10nF; C_0402_1005Metric
C35: 33uF; C_0805_2012Metric
D1: PESD5V0S1BA; D_SOD-323
D2: IR LED (SMT / L0AJ-LSG1 set); IRLED_L0AJ_3311
D3: BLUE; LED_0603_1608Metric
EC1: 11mm encoder; ENC_Mouse_11mm
F1: PTC 1A; Fuse_1206_3216Metric
FB1: 600R@100MHz; L_1206_3216Metric
J1: USB4105-GF-A; USB_C_Receptacle_HRO_TYPE-C-31-M-12
J2: JST S2B-PH-K; JST_PH_S2B-PH-K_1x02_P2.00mm_Horizontal
J3: SWD 1x05; PinHeader_1x05_P2.54mm_Vertical
L1: 10uH; L_0603_1608Metric
L2: 15nH; L_0402_1005Metric
L3: 4.7nH; L_0402_1005Metric
L4: 2.2nH; L_0402_1005Metric
MH1, MH2, MH3: M3; MountingHole_3.2mm_M3
Q1, Q2: AO3400A; SOT-23
Q3: AO3401A; SOT-23
R1, R2: 5.1k; R_0402_1005Metric
R3, R11, R13, R15, R16, R17, R18, R19, R20, R21: 10k; R_0402_1005Metric
R4: 3.24k; R_0402_1005Metric
R5: 2.0k; R_0402_1005Metric
R6, R7, R9, R10, R24: 100k; R_0402_1005Metric
R8: 200k; R_0402_1005Metric
R12: 1k; R_0402_1005Metric
R14: 10k (DNP); R_0402_1005Metric
R22: 18R 1%; R_0402_1005Metric
R23: 3.3k 1%; R_0402_1005Metric
R25: 47k; R_0402_1005Metric
SW1, SW2, SW3, SW4, SW5: Kailh GM 8.0; SW_Kailh_GM8_D2F
TP1: TP1; TestPoint_Pad_1.0x1.0mm
TP2: TP2; TestPoint_Pad_1.0x1.0mm
TP3: TP3; TestPoint_Pad_1.0x1.0mm
TP4: TP4; TestPoint_Pad_1.0x1.0mm
TP5: TP5; TestPoint_Pad_1.0x1.0mm
TP6: TP6; TestPoint_Pad_1.0x1.0mm
U2: BQ24074; VQFN-16-1EP_3x3mm_P0.5mm_EP1.68x1.68mm_ThermalVias
U3: XC6219B192MR; SOT-23-5
U4: nRF52833-QIAA (Bxx+); Nordic_AQFN-73-1EP_7x7mm_P0.5mm
U5: PAW3311DB-T2MU; PAW3311DB_iDIP8_L0AJ
Y1: 32MHz CL=8pF; Crystal_SMD_2016-4Pin_2.0x1.6mm
Y2: 32.768kHz CL=9pF; Crystal_SMD_3215-2Pin_3.2x1.5mm

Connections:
1V9: C5.1, C6.1, FB1.1, U3.5
1V9_A: C7.1, C8.1, C13.1, C14.1, C15.1, C16.1, C17.1, C25.1, C26.1, C35.1, FB1.2, J3.1, R6.1, R7.1, R11.1, R13.1, R14.1, R15.1, R16.1, R17.1, R18.1, R19.1, R20.1, R21.1, R22.1, U4.A22, U4.AD14, U4.AD23, U4.B1, U4.W1, U4.Y2, U5.3
ANT: C22.1, L3.1, U4.H23
BTN_LEFT: C28.1, R15.2, SW1.2, U4.J1
BTN_RIGHT: C29.1, R16.2, SW2.2, U4.W24
BTN_SIDE_BACK: C30.1, R17.2, SW3.2, U4.U24
BTN_SIDE_FWD: C31.1, R18.2, SW4.2, U4.M2
CC1: J1.A5, R1.1
CC2: J1.B5, R2.1
DCC: L1.1, U4.B3
DCC_L: L1.2, L2.1
DEC1: C9.1, U4.C1
DEC3: C10.1, U4.D23
DEC4_6: C11.1, C12.1, L2.2, U4.B5, U4.E24
ENC_A: C32.1, EC1.A, R19.2, U4.N1
ENC_B: C33.1, EC1.B, R20.2, U4.T2
ENC_SW: R21.2, SW5.2, U4.U1
GND: ANT1.2, C1.2, C2.2, C3.2, C4.2, C5.2, C6.2, C7.2, C8.2, C9.2, C10.2, C11.2, C12.2, C13.2, C14.2, C15.2, C16.2, C17.2, C18.2, C19.2, C20.2, C21.2, C22.2, C23.2, C24.2, C25.2, C26.2, C27.2, C28.2, C29.2, C30.2, C31.2, C32.2, C33.2, C34.2, C35.2, C36.2, D1.2, EC1.C, J1.A1, J1.A12, J1.B1, J1.B12, J1.SH, J2.2, J3.5, Q1.2, Q2.2, R1.2, R2.2, R3.2, R4.2, R5.2, R9.2, R10.2, R24.2, SW1.1, SW2.1, SW3.1, SW4.1, SW5.1, U2.4, U2.6, U2.8, U2.17, U3.2, U4.B7, U4.EP, U4.F23, U5.6, Y1.2, Y1.4
ILIM: R4.1, U2.12
ISET: R5.1, U2.16
LDO_IN: C4.1, F1.2, U3.1, U3.3
LED_A: D3.1, R12.2
LED_DRV: D2.1, R22.2
LED_K: D3.2, Q2.3
LED_STAT: Q2.1, R24.1, U4.AD8
PGOOD: R7.2, U2.7, U4.AD10
RF1: C23.1, L3.2, L4.1
RF_FEED: ANT1.1, C24.1, L4.2
SENS_LED: D2.2, U5.1
SENS_MOTION: R14.2, TP4.1, U4.A14, U5.5
SENS_NCS: R13.2, U4.AD12, U5.8
SENS_SDIO: R23.2, TP2.1, U4.AD20, U5.7
SPI_MOSI: R23.1, TP3.1, U4.AD18
SPI_SCK: TP1.1, U4.AD16, U5.4
STAT: R6.2, U2.9, U4.AC9
SWDCLK: J3.3, U4.AA24
SWDIO: J3.2, U4.AC24
TS: R3.1, U2.1
VBAT: C36.1, J2.1, Q3.2, R25.1, TP5.1, U2.2, U2.3
VBAT_EN: Q1.1, R10.1, U4.AD22
VBAT_SENSE: R8.2, R9.1, U4.A12
VBAT_SW: Q3.3, R8.1
VBAT_SW_G: Q1.3, Q3.1, R25.2
VBUS: C1.1, C2.1, D1.1, J1.A4, J1.A9, J1.B4, J1.B9, U2.13
VDDREG: C27.1, C34.1, U5.2
VSYS: C3.1, F1.1, R12.1, TP6.1, U2.5, U2.10, U2.11
XC1: C18.1, U4.B24, Y1.1
XC2: C19.1, U4.A23, Y1.3
XL1: C20.1, U4.D2, Y2.1
XL2: C21.1, U4.F2, Y2.2
nRESET: J3.4, R11.2, U4.AC13

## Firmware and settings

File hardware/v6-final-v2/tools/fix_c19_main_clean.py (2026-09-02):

#!/usr/bin/env python3
"""Fix C19-2 GND island on main hakai_mouse_v6.kicad_pcb (not backup).

Strategy:
  1) Remove XC1 B.Cu diagonal that runs through C19 pad2
     (151.413,119.546)-(153.214,117.746).
  2) Reroute XC1 B around the crystal-area B congestion by going
     WEST first (clear of PGOOD/SWDIO/VBAT_SENSE diagonals), NORTH
     past 1V9/VBAT, EAST past VBAT_SENSE, then SOUTH to the existing
     XC1 B join:
       via @151.413,119.546
         -> H to x=148.50
         -> V to y=114.80
         -> H to x=157.20
         -> V to y=117.746
         -> H to existing join @155.623,117.746
  3) Place GND via-in-pad on C19-2 @152.50,118.52 so F pad
     reaches B.Cu GND pour once XC1 is off the pad.

Does not touch pcb_final_proto_backup.
"""
from __future__ import annotations

import json
import os
import subprocess
import sys
from collections import Counter

import pcbnew

V6 = os.path.normpath(os.path.join(os.path.dirname(os.path.abspath(__file__)), ".."))
PCB = os.path.join(V6, "hakai_mouse_v6.kicad_pcb")
KCLI = r"C:\Program Files\KiCad\10.0\bin\kicad-cli.exe"
OUT = os.path.join(V6, "build", "drc_after_c19_clean.json")

VIA_D, VIA_DRILL = 0.45, 0.20
MM = pcbnew.FromMM
BC = int(pcbnew.B_Cu)

# Detour waypoints (mm)
X_WEST = 148.50
Y_NORTH = 114.80
X_EAST = 157.20
Y_JOIN = 117.746
X_JOIN = 155.623
X_VIA, Y_VIA = 151.413, 119.546


def TOMM(v):
    return v / 1e6


def V(x, y):
    return pcbnew.VECTOR2I(MM(x), MM(y))


def near(a, b, eps=0.05):
    return abs(a - b) < eps


def main():
    print("Loading", PCB)
    board = pcbnew.LoadBoard(PCB)

    nets = {}
    for fp in board.GetFootprints():
        for p in fp.Pads():
            n = p.GetNetname()
            if n and n not in nets:
                nets[n] = p.GetNet()
    gnd, xc1 = nets["GND"], nets["XC1"]

    def add_via(x, y, net):
        v = pcbnew.PCB_VIA(board)
        v.SetPosition(V(x, y))
        v.SetDrill(MM(VIA_DRILL))
        try:
            v.SetWidth(MM(VIA_D))
        except TypeError:
            v.SetWidth(pcbnew.F_Cu, MM(VIA_D))
            v.SetWidth(pcbnew.B_Cu, MM(VIA_D))
        v.SetViaType(pcbnew.VIATYPE_THROUGH)
        v.SetLayerPair(pcbnew.F_Cu, pcbnew.B_Cu)
        v.SetNet(net)
        board.Add(v)

    def add_seg(x1, y1, x2, y2, lay, net, w):
        t = pcbnew.PCB_TRACK(board)
        t.SetStart(V(x1, y1))
        t.SetEnd(V(x2, y2))
        t.SetLayer(lay)
        t.SetWidth(MM(w))
        t.SetNet(net)
        board.Add(t)

    # --- 1) Remove XC1 B diagonal under C19 + any prior experimental segs ---
    removed = 0
    for t in list(board.Tracks()):
        if t.GetClass() == "PCB_VIA":
            if t.GetNetname() == "GND":
                p = t.GetPosition()
                if near(TOMM(p.x), 152.50, 0.05) and near(TOMM(p.y), 118.52, 0.05):
                    board.Remove(t)
                    removed += 1
                    print("removed prior GND VIP @ C19-2")
            continue
        if t.GetNetname() != "XC1":
            continue
        if int(t.GetLayer()) != BC:
            continue
        s, e = t.GetStart(), t.GetEnd()
        sx, sy, ex, ey = TOMM(s.x), TOMM(s.y), TOMM(e.x), TOMM(e.y)

        # Original diagonal under C19 pad2
        is_diag = (
            near(sx, 151.413, 0.05)
            and near(sy, 119.546, 0.05)
            and near(ex, 153.214, 0.05)
            and near(ey, 117.746, 0.05)
        ) or (
            near(ex, 151.413, 0.05)
            and near(ey, 119.546, 0.05)
            and near(sx, 153.214, 0.05)
            and near(sy, 117.746, 0.05)
        )
        # Any prior detour / experiment segments we may have added
        is_prior = (
            near(sx, X_WEST, 0.15)
            or near(ex, X_WEST, 0.15)
            or near(sx, X_EAST, 0.15)
            or near(ex, X_EAST, 0.15)
            or near(sy, Y_NORTH, 0.15)
            or near(ey, Y_NORTH, 0.15)
            or near(sy, 115.50, 0.15)
            or near(ey, 115.50, 0.15)
            or near(sx, 156.30, 0.15)
            or near(ex, 156.30, 0.15)
            or (
                near(sx, 153.214, 0.05)
                and near(ex, 153.214, 0.05)
                and min(sy, ey) < 117.2
            )
            or (
                near(sx, 151.413, 0.05)
                and near(ex, 151.413, 0.05)
                and min(sy, ey) < 117.0
            )
            or (
                near(sx, 151.413, 0.05)
                and near(sy, 119.546, 0.05)
                and near(ex, 153.214, 0.08)
                and ey < 118.0
            )
            or (
                near(ex, 151.413, 0.05)
                and near(ey, 119.546, 0.05)
                and near(sx, 153.214, 0.08)
                and sy < 118.0
            )
        )

        if is_diag or is_prior:
            board.Remove(t)
            removed += 1
            print(f"XC1: removed B ({sx:.3f},{sy:.3f})-({ex:.3f},{ey:.3f})")

    print(f"removed {removed} track(s)")

    # --- 2) XC1 B detour: west -> north -> east -> south to join ---
    add_seg(X_VIA, Y_VIA, X_WEST, Y_VIA, BC, xc1, 0.15)
    add_seg(X_WEST, Y_VIA, X_WEST, Y_NORTH, BC, xc1, 0.15)
    add_seg(X_WEST, Y_NORTH, X_EAST, Y_NORTH, BC, xc1, 0.15)
    add_seg(X_EAST, Y_NORTH, X_EAST, Y_JOIN, BC, xc1, 0.15)
    add_seg(X_EAST, Y_JOIN, X_JOIN, Y_JOIN, BC, xc1, 0.15)
    print(
        f"XC1: B detour west={X_WEST} north={Y_NORTH} east={X_EAST} -> join {X_JOIN},{Y_JOIN}"
    )

    # --- 3) C19-2 GND via-in-pad ---
    add_via(152.50, 118.52, gnd)
    print("C19: GND via-in-pad @ (152.50, 118.52)")

    print("zone fill...")
    pcbnew.ZONE_FILLER(board).Fill(board.Zones())
    board.Save(PCB)
    print("Saved", PCB)

    subprocess.run(
        [KCLI, "pcb", "drc", "--format", "json", "-o", OUT, PCB],
        capture_output=True,
    )
    d = json.load(open(OUT, encoding="utf-8"))
    unc = d.get("unconnected_items", [])
    viol = d.get("violations", [])
    sev = Counter(v.get("severity") for v in viol)
    typ = Counter(v.get("type") for v in viol)
    print(f"DRC unconnected={len(unc)} viol={len(viol)} sev={dict(sev)}")
    for k, n in typ.most_common():
        print(f"  {k}: {n}")
    hard = []
    for v in viol:
        if v.get("severity") != "error":
            continue
        items = v.get("items", [])
        descs = [i.get("description", "")[:90] for i in items]
        p = items[0].get("pos", {}) if items else {}
        print(f" ERR {v.get('type')}: {' | '.join(descs)} @({p.get('x')},{p.get('y')})")
        if v.get("type") in {
            "shorting_items",
            "tracks_crossing",
            "clearance",
            "hole_to_hole",
            "copper_edge_clearance",
        }:
            hard.append(v)
    for u in unc:
        print(" UNCONN", [i.get("description", "")[:80] for i in u.get("items", [])])

    ok = len(unc) == 0 and not hard
    print("SUCCESS" if ok else f"PARTIAL unc={len(unc)} hard={len(hard)}")
    return 0 if ok else 1


if __name__ == "__main__":
    sys.exit(main())

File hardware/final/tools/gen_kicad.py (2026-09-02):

#!/usr/bin/env python3
"""
HAKAI Wireless Gaming Mouse Rev 2.0 - KiCad schematic generator.
Emits a flat single-sheet .kicad_sch (file version 20231120, KiCad 8 format;
opens in KiCad 8/9/10) plus a minimal .kicad_pro.

Connectivity model: no drawn wires -- every pin is connected either to a
global label, a power symbol, or a no_connect marker placed exactly on the
pin's electrical endpoint. Netlist-exact and ERC-checkable.

Data provenance:
  nRF52833-QIAA ball map + all decoupling/RF values: Nordic PS v1.7 Table 62 +
    sect. 7.3, cross-checked against PCA10100 DK 2.0.0 design files.
  BQ24074: TI SLUS810N.  XC6219B332MR: Torex datasheet.
  USB4105 / PEC11R / D2F / 2N7002 / PESD5V0S1BA / JST PH: vendor datasheets.
  PAW3311DB: VERIFIED against PixArt datasheet v1.0 (1A009EN, 15 Nov 2022):
    8-pin DB, VDD 1.8-2.1V (ABS MAX 2.1V), 3-wire SDIO SPI (Fig.6 MISO/MOSI-R1
    bridge), VDDREG bypass-only, MOTION push-pull, LED chain VLED->18R->IR->pin1.
  System consequence: whole design runs on a single 1.9V rail (XC6219B192MR);
    nRF52833 operates 1.7-3.6V so MCU and sensor share it with no level shift.
"""
import uuid as _uuid
import os

def u():
    return str(_uuid.uuid4())

ROOT_UUID = "df71f9f2-97ab-4d7b-a476-8fc54408afff"  # stable: keeps .kicad_pro sheet list valid across regenerations
PROJECT = "hakai_mouse_final"
# package-relative: the generator always writes the project folder above tools/
OUT_DIR = os.path.normpath(os.path.join(os.path.dirname(os.path.abspath(__file__)), ".."))

F = '(effects (font (size 1.27 1.27)))'
FH = '(effects (font (size 1.27 1.27)) (hide yes))'
GRID = 1.27


def snap(v):
    return round(round(v / GRID) * GRID, 4)


def fmt(v):
    r = round(v, 4)
    if r == int(r):
        return str(int(r))
    return f"{r:g}"


# --------------------------------------------------------------------------
# Library symbols
# --------------------------------------------------------------------------

class LibPin:
    def __init__(self, number, name, side, row, etype="passive"):
        self.number = str(number)
        self.name = name
        self.side = side
        self.row = row
        self.etype = etype


class LibPart:
    """IC / multi-pin part, pins on left/right sides of a rectangle."""

    def __init__(self, name, ref_prefix, halfwidth, description="", pin_len=2.54):
        self.name = name
        self.ref = ref_prefix
        self.w2 = snap(halfwidth)
        self.desc = description
        self.pin_len = pin_len
        self.pins = []

    def pin(self, number, name, side, row, etype="passive"):
        self.pins.append(LibPin(number, name, side, row, etype))
        return self

    def _geom(self):
        rows = 1 + max(p.row for p in self.pins)
        h2 = snap((rows + 1) * 2.54 / 2.0)
        top_y = h2 - 2.54
        return h2, top_y

    def pin_local(self, number):
        p = next(q for q in self.pins if q.number == str(number))
        h2, top_y = self._geom()
        py = top_y - p.row * 2.54
        if p.side == 'L':
            px = -(self.w2 + self.pin_len)
        else:
            px = self.w2 + self.pin_len
        return px, py, p.side

    def sexpr(self):
        h2, _ = self._geom()
        s = []
        s.append(f'    (symbol "hakai:{self.name}"')
        s.append('      (pin_names (offset 1.016)) (exclude_from_sim no) (in_bom yes) (on_board yes)')
        s.append(f'      (property "Reference" "{self.ref}" (at 0 {fmt(h2 + 2.54)} 0) {F})')
        s.append(f'      (property "Value" "{self.name}" (at 0 {fmt(-(h2 + 2.54))} 0) {F})')
        s.append(f'      (property "Footprint" "" (at 0 0 0) {FH})')
        s.append(f'      (property "Datasheet" "" (at 0 0 0) {FH})')
        s.append(f'      (property "Description" "{self.desc}" (at 0 0 0) {FH})')
        s.append(f'      (symbol "{self.name}_0_1"')
        s.append(f'        (rectangle (start {fmt(-self.w2)} {fmt(h2)}) (end {fmt(self.w2)} {fmt(-h2)})'
                 ' (stroke (width 0.254) (type default)) (fill (type background)))')
        s.append('      )')
        s.append(f'      (symbol "{self.name}_1_1"')
        for p in self.pins:
            px, py, side = self.pin_local(p.number)
            ang = 0 if side == 'L' else 180
            s.append(f'        (pin {p.etype} line (at {fmt(px)} {fmt(py)} {ang}) (length {fmt(self.pin_len)})')
            s.append(f'          (name "{p.name}" {F})')
            s.append(f'          (number "{p.number}" {F})')
            s.append('        )')
        s.append('      )')
        s.append('    )')
        return "\n".join(s)


class LibPassive:
    """Vertical 2-pin part: pin 1 endpoint (0,+ext), pin 2 (0,-ext), lib Y-up."""

    def __init__(self, name, ref_prefix, description="", body="rect",
                 ext=5.08, pin_len=2.54, p1name="1", p2name="2"):
        self.name = name
        self.ref = ref_prefix
        self.desc = description
        self.body = body
        self.ext = ext
        self.pin_len = pin_len
        self.p1name, self.p2name = p1name, p2name

    def pin_local(self, number):
        if str(number) == "1":
            return 0.0, self.ext, 'T'
        return 0.0, -self.ext, 'B'
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

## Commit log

2026-09-02 Import Hakai project: hardware revisions, site, docs and tools
    Reorganise the working tree into grouped root folders with one folder
    per design revision:
    hardware/{rev2,v5,final,v6,v6-final-v2} KiCad projects, chronological
    site/ static product site
    docs/ design notes / schematic write-ups
    tools/ Blender MCP addon and helpers
    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
    [BOM_hakai_mouse_final.csv, BOM_hakai_mouse_rev2.csv, BOM_hakai_mouse_v5.csv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]
2026-09-02 Refill zones on v6-final-v2 and add fab-ready gerber package
    The saved zone fill predated the SWDIO / VBAT_SENSE reroutes, so the
    stored GND pour overlapped both nets at 0.0000 mm clearance and intruded
    into the MH3 keepout. Gerber export plots the saved fill, so any export
    taken from the previous state would have produced boards with SWDIO and
    VBAT_SENSE shorted to ground.
    Refilled with the project's own design rules loaded (SETTINGS_MANAGER
    LoadProject before LoadBoard), so netclass constraints and the custom
    qfn_escape_* rules apply. Refilling without the project loaded silently
    falls back to defaults and produces a fill that fails DRC in 1171 places.
    Verification:
    DRC without --refil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
    [hakai_mouse_v6-B_Cu.gbl, hakai_mouse_v6-B_Mask.gbs, hakai_mouse_v6-B_Paste.gbp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]
